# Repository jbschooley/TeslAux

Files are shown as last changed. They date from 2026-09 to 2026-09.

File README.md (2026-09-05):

# TeslAux

**Play audio from a phone through a Tesla's speakers, over USB.**

A Tesla has no aux input. It does have a USB port that accepts Tesla's own
cabin microphone — the CaraokeMic — and routes whatever that microphone hears
into the cabin speakers. TeslAux clones that microphone precisely enough that the
car accepts it, then feeds it real audio instead of a microphone.

The result is a wired audio input: anything that can play into a USB audio
output can play through the car. Wired, so unlike Bluetooth it is not
resampled, not re-encoded, and not subject to codec latency.

## How it works

```
phone ──USB──> [source board] ──I²S──> [car board] ──USB──> Tesla
               a USB audio output      a clone of the CaraokeMic
```

Two boards, because the phone and the car are both USB *hosts* — a device has to
be a USB *peripheral* to each, and one USB controller cannot do both. They are
joined by I²S, which carries the audio between them as plain PCM with no
conversion at any point.

The source board's clock is steered to follow the phone, so the phone and the
I²S link run on one clock. The only remaining clock difference — against the
car — is absorbed by varying the size of each USB packet, which loses no samples
at all.

## Build and flash

Two identical **RP2040-Zero** boards, about $3 each. Solder four signals and a
ground between them:

| source board | | car board |
|---|---|---|
| GPIO12 | → | GPIO10 (DATA) |
| GPIO11 | → | GPIO11 (BCK) |
| GPIO10 | → | GPIO12 (SHIELD) |
| GPIO9 | → | GPIO13 (LRCK) |
| GND | → | GND |

The pins are the bottom row, so the two boards can be soldered edge to edge with
one rotated 180 degrees — every pair above sums to 22, which is what facing pads
do. Four-inch jumpers were corrupting one sample in roughly every 1,400: the
right channel replaced by its own sign bit, up to 44% of full scale in a single
sample, which is audible as a pop every few minutes.

SHIELD carries no signal. The source holds it low so a driven conductor sits
between BCK and LRCK, which is where the coupling was. `rp2040/src/pins.rs` has
the measurement and refuses to build if the map stops being physically possible.

Ground is not optional — the boards are powered from different USB ports.

```sh
cd rp2040 && ./build-uf2.sh
```

Then hold BOOTSEL while plugging each board into a computer and copy its image
across. Use `cp`, not Finder: the bootloader reboots the instant the last block
lands, which Finder treats as a disk being yanked out.

```sh
# the board the phone plugs into
cp rp2040/teslamic-rp-source-ultralow.uf2 /Volumes/RPI-RP2/

# the board that plugs into the car
cp rp2040/teslamic-rp-car-elastic-lowlat.uf2 /Volumes/RPI-RP2/
```

The phone will show a USB audio output called **TeslAux Bridge**. Plug the car
board into the car's data port and the mic icon appears.

Each board has an onboard RGB LED: **green** streaming, **blue** waiting for
audio, **red** a fault. [`rp2040/FLASHING.md`](rp2040/FLASHING.md) has every
image, the LED codes in full, and the diagnostic builds.

### A simpler version is coming

A **PCM2706** USB-to-I²S bridge chip can replace the source board entirely. It is
a fixed-function part with no firmware, and it recovers the host's clock in
hardware rather than in a software control loop — which should be both more
reliable and about 5 ms lower latency than the two-board version. That leaves one
RP2040 plus a ~$10 module. The car-side firmware already supports it and follows
whatever sample rate it delivers; it has not been tested yet.

## Verified bit-exact

The two-board rig has been measured, not just listened to: **8,352,000 frames
across three consecutive cold boots, delivered from an Android phone to a Mac
through both boards, identical to the source file, sample for sample.** See `rp2040/TESTING.md` for
the method and `tools/bitcompare.py` for the tool.

## What the car accepts

Findings from the car itself, not from documentation. Several contradict what
this project believed for months — the corrections are noted.

### The device must look like a CaraokeMic

The car runs a driver written for one specific device and checks for it. Getting
the audio right is not enough; get the descriptors wrong and it shows
"unsupported USB microphone" and disconnects after about 60 seconds.

What has to match, verified against a real unit dumped over libusb
(see [`real_mic_dump.md`](real_mic_dump.md)):

* **VID `0x1235`, PID `0x0002`**, and the manufacturer, product and serial
  strings. The serial is 40 bytes, which makes the string descriptor 162 bytes —
  a 128-byte control buffer silently breaks enumeration.
* **Four interfaces**: AudioControl, AudioStreaming, and *two* HID interfaces.
* **IF2 is a HID keyboard** with the standard 65-byte boot-keyboard report
  descriptor. Not telemetry, as was assumed for months — the mic's button sends
  keystrokes.
* **IF3 is an endpoint-less vendor HID**, usage page `0xFF00`, usage `0x55AA`,
  with an exact 36-byte report descriptor and an 8-byte Feature report reading
  `00 01 00 03 03 00 08 00`. **This is the one that matters.** The car writes
  `A5 5A`-framed configuration to it and validates what comes back. Cloning it
  byte for byte is what defeats the popup.

What does *not* have to match: the endpoint numbers, the audio topology (a plain
microphone → USB-streaming terminal pair works, without the real mic's feature
and selector units), `bcdUSB`, `bcdHID`, and `wMaxPacketSize`.

### Audio formats

Retested after fixing two transport bugs that had been corrupting everything we
sent. The earlier conclusion that the car was "48 kHz-family only" was wrong —
it was our own corruption, and 44.1 kHz was simply the rate most exposed to it.

| | |
|---|---|
| 32 kHz, 44.1 kHz, 48 kHz, 16-bit | clean — retested after the transport fixes |
| 96 kHz, 16-bit | clean — retested |
| 192 kHz, 16-bit | plays, with a click roughly every 2 s (not diagnosed) |
| stereo | yes |
| more than 2 channels | only the first two are ever played |
| **24-bit** | **unverified** — see below |

**24-bit is an open question, not a result.** It was tested in July and appeared
clean at 48 and 96 kHz, but that predates the two transport bugs being found, and
those July tests used a 1 kHz tone at 48 kHz — exactly one cycle per USB packet,
and therefore blind to the packet corruption by construction. The same test
signal also reported 48 kHz as "clean" while every packet was being mangled. So
the July result carries no information either way.

`t114/teslamic-48k-24bit.uf2` and `teslamic-96k-24bit.uf2` are rebuilt against
the fixed firmware with a 997 Hz tone (deliberately not packet-periodic) if you
want to settle it. Note 192 kHz at 24-bit is impossible regardless: 1152 bytes
per frame against the 1023-byte full-speed isochronous limit.

It does not currently matter for the shipping firmware, which is 16-bit
throughout — the PCM2706 is 16-bit only, and the RP2040 path is built around
16-bit samples.

### Variable packet sizes

**The car accepts isochronous packets that change size from frame to frame.**
Verified with a build that alternates 47 and 49 samples on *every* frame, ~500×
harsher than real clock drift, playing cleanly for ten minutes.

This is what makes the design work: the difference between our clock and the
car's is absorbed by sending one more or one fewer sample when needed, so no
sample is ever dropped, duplicated or resampled.

### Latency

About 8 ms through both boards — USB frame quantisation, and enough buffer to
cover one packet at each hop.

That is not what you will hear. **The car's own audio pipeline adds roughly
100 ms**, measured in July and not reachable from the device, and the phone adds
10–50 ms of its own buffering. Our share is a few percent of the total, which is
worth knowing before optimising it further.

## Repository layout

| | |
|---|---|
| [`rp2040/`](rp2040) | the firmware to use — both boards build from one crate |
| [`t114/`](t114) | the original nRF52840 prototype, where the descriptors and the transport bugs were worked out |
| [`tools/`](tools) | UF2 packaging, and analysis scripts for recorded audio |
| [`RESEARCH.md`](RESEARCH.md) | how the CaraokeMic was reverse engineered |
| [`real_mic_dump.md`](real_mic_dump.md) | raw descriptor dump from a real unit |

## Licence

MIT throughout — see [`LICENSE`](LICENSE).

[`NOTICE.md`](NOTICE.md) records the provenance of two pieces: the T114's ST7789
driver, ported from an AGPL project and relicensed MIT here by its copyright
holder, and `tools/uf2conv.py`, from Microsoft's uf2 project.

"Tesla", "TeslaMic" and "CaraokeMic" are trademarks of Tesla, Inc. This project
is independent and not affiliated with or endorsed by Tesla.

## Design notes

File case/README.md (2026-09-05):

# Case for the soldered pair

Two RP2040-Zeros soldered end to end — castellations butted, component sides up,
a USB-C port at each outer end, the I²S link running across the joint.

```
    USB-C -> [RP2040-Zero | RP2040-Zero] <- USB-C
     phone              ^ joint             car
```

| file | triangles | size |
|---|---|---|
| `rp2040_soldered_case.stl` | 2,746 | 53.2 x 24.2 x 7.8 mm |
| `rp2040_soldered_lid.stl` | 3,490 | 53.2 x 24.2 x 7.6 mm |

53.2 x 24.2 x 9.4 mm closed. The lid is flush with the base — no lip, so the
seam is the only purchase for opening it.

## Printing

Both parts print without supports.

- **Base:** flat on the bed as oriented.
- **Lid:** outer face down, so the tabs and posts point up.

The rounded edges sit against the bed either way. A quarter round leaves the face
horizontally, so the first few layers grow outward fast — about 0.24 mm per
0.2 mm layer at the steepest, within what a 0.4 mm extrusion bridges, but slow
the first few layers if the edge comes out rough.

## Fit notes

These are the second revision, after a test print. What changed:

- The board is **0.8 mm thick, not 1.6** — measured off the real thing, which is
  why the case got shorter despite everything else growing.
- A SOT-23 on the underside beside each USB port landed on the support ring; the
  ring is now cut away 8 mm across, 9 mm in from the cavity wall at each end.
- The USB sill was too low once the thickness was corrected, and sits 0.3 mm
  below flush so a sill printed slightly proud cannot foul the connector.
- Two ribs bracing the joint from underneath fouled the crystals, which sit 4–5 mm
  either side of it. Gone; the ring's long runs carry the board across the gap.

Only the two STLs are here. The generator that produced them, and the full write
-up of the revisions, live outside this repo — worth bringing in if the case ever
needs changing, since these files cannot be regenerated without it.

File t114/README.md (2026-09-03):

# T114 / nRF52840 — the original prototype

**This is not the firmware to use.** It is where the project started, and where
the hard problems were solved: the descriptor set the car validates, and both
isochronous transport bugs. The shipping firmware is in [`../rp2040`](../rp2040).

It still works, and it is still the most car-proven code here — it has been
accepted by a real Tesla since July. It is kept because:

* it is the reference the RP2040 descriptors were copied from, byte for byte;
* it has a hardware I2S slave peripheral, so it needs no PIO, which makes it a
  useful cross-check if the RP2040's I2S is ever suspect;
* it has an onboard TFT, which is what the `usb-spy` build draws the car's USB
  control requests on. That is how the IF3 config protocol was found.

What it does **not** have is an audio input path — it emulates the mic and
generates test tones, but nothing wires I2S capture into its isochronous pump.
That work went into the RP2040 firmware instead.

Hardware: Heltec Mesh Node T114 (nRF52840 + SX1262). Flash by double-tapping
RESET and dragging a `.uf2` onto the drive that appears.

---

Firmware that makes a **Heltec Mesh Node T114** enumerate over USB as Tesla's
cabin microphone, to test whether the car will show its **MIC overlay icon**.

Identity + descriptors are cloned from the TeslaMic dump in the [r/hardwarehacking
thread](https://www.reddit.com/r/hardwarehacking/comments/1ok256p/going_down_a_rabbit_hole_wondering_where_to_start/):

| Field | Value |
|---|---|
| VID:PID | `1235:0002` |
| Manufacturer | `TeslaMic_T004_OTA_231008` |
| Product | `TeslaMic` |
| Max power | 500 mA |
| Audio | USB Audio Class 1.0 — 48 kHz, 16-bit, **stereo**, 192 B/1 ms iso IN |

## Status — WORKING ✅ (popup solved 2026-07-14)

`teslamic-hid.uf2` runs in the car with the **mic icon, working audio, and no
"unsupported USB microphone" popup / disconnect**. The HID interfaces are a
byte-exact clone of a real TeslaMic (dumped over libusb — see `real_mic_dump.md`):
IF2 is a HID keyboard, IF3 is an endpoint-less vendor HID (Usage 0x55AA) whose
report descriptor + Feature report the car validates. It also enumerates on macOS
as a 2-channel / 48 kHz input named `TeslaMic`.

Remaining work is product polish (an I²S line-in front-end to stream real audio)
and the ~100 ms **Tesla-side** latency (not fixable on the device — our end is
~1–2 ms; it's the car's audio pipeline).

Four flashable builds:

| File | Behaviour |
|---|---|
| **`teslamic.uf2`** | Enumerates **and streams silence** — 192 B of zeros per USB frame out the iso endpoint, so it looks like a mic that's actively capturing. Try this in the car. |
| **`teslamic-sine.uf2`** | Same, but emits a **1 kHz sine while the USER button (P1_10) is held**, silence when released. Each new press **alternates the channel**: press 1 = LEFT, press 2 = RIGHT, press 3 = LEFT, … (other channel silent). Good for confirming the audio path and checking L/R routing. |
| **`teslamic-hid.uf2`** | Everything: the button-triggered L/R sine **plus a HID interface (IF2) streaming an 8-byte heartbeat** — an attempt to defeat the ~60 s "unsupported USB microphone" popup (see [The popup](#the-popup-hid-heartbeat)). Built with `--features hid-heartbeat,sine-button`. |
| `teslamic-enum-only.uf2` | Enumerates only (no iso data). Fallback if a streaming build misbehaves. Tested to enumerate on macOS. |

## The popup (HID heartbeat)

The genuine TeslaMic exposes two HID interfaces (an 8-byte interrupt-IN status
stream + a control/feature "settings" interface) that this project's audio-only
builds don't. The car shows the mic icon and plays audio, but after ~60 s pops
"unsupported USB microphone" — most likely a **keepalive/telemetry watchdog**
timing out (a static descriptor check would fail instantly, not after a minute).

`teslamic-hid.uf2` adds **IF2** (8-byte interrupt IN, `poll_ms = 1`, matching the
dump) and streams a report continuously, with a rolling counter in byte 0 so a
liveness watchdog sees changing data.

**This is a blind guess.** The dump doesn't include the HID report descriptors or
the report *contents*, so if the car validates specific values (rather than just
"is something reporting"), this won't be enough — it would need a `usbhid-dump` +
USB trace from a real or clone TeslaMic. The IF3 "settings" interface is also not
implemented yet. Combine with the tone build via
`--features hid-heartbeat,sine-button` if you want to test audio and the popup
together.

Tesla: Sees the device as a microphone input and shows the mic icon. The sine wave plays through the car's audio system.

However, there is a noticeable delay (estimating around 100ms) between pressing the button and hearing the sine wave. This is much better than Bluetooth, but not instantaneous enough for real-time audio (like playing an instrument). The only way to fix this would be to get Tesla's engineers to reduce the buffering. I'm surprised they haven't done this already because the delay is noticeable when using the official Tesla Caraoke Mic.

After a minute, it disconnects and the car shows an unsupported USB microphone popup. I assume this is because the TeslaMic firmware is sending some telemetry over the HID interface that this firmware does not implement. I don't have an official or clone mic to use to reverse engineer this interface yet.

## USB spy — on-screen request logger (`teslamic-spy.uf2`)

To reverse-engineer the popup without a real mic, this build turns the T114 into
its own USB analyzer. It's the full mic + HID device (`--features usb-spy`, which
implies `hid-heartbeat`), plus a spy that **logs every USB control request the car
sends to the onboard ST7789 TFT in real time**. Flash it, plug into the car, and
watch the screen (it lights ~1.5 s after boot).

Each line is one control request/event:

```
CONFIGURED=1            device configured
SET_IF if1 alt1         host selected AudioStreaming alt-1 (starts audio)
O 21 r09 v0200 i2 l8 d05   ctrl-OUT bmReqType=0x21 bReq=0x09(SET_REPORT)
                            wValue=0x0200 iface=2 len=8 firstbyte=0x05
I a1 r01 v0100 i2 l8       ctrl-IN  bmReqType=0xA1 bReq=0x01(GET_REPORT) ...
```

`bmReqType` decodes as: `0x21` = host→device, class, interface; `0xA1` = the
device→host read. Anything the car sends to **interface 2** (our HID) — especially
`SET_REPORT`/`GET_REPORT` with their `wValue` and data byte — is the handshake
we're missing. Read those off the screen (or photograph it) right up to the popup,
and we can implement the HID interface to match instead of guessing.

Notes/limits: the spy observes **class/vendor** requests (the interesting ones) plus
config + alt-setting changes; it doesn't see plain standard requests. The screen
shows the most recent ~11 events; the ring buffer holds 32.

## Format test builds

The audio format is a **build-time parameter** (`build.rs` reads env vars), so any
feasible rate / channel count / bit depth is one build away. All these use
`sine-button`, so the tone plays while the USER button is held; each press steps
the tone to the **next channel** (at 2ch = L/R; at 4ch = cycles all four), which
is how you check the car's channel mapping.

| File | Format | Car result | Env |
|---|---|---|-----|
| `teslamic-48k-24bit.uf2` | 48 kHz / 2ch / 24 | ❔ July result is uninformative, not retested | `TESLAMIC_BITS=24` |
| `teslamic-96k.uf2` | 96 kHz / 2ch / 16 | ✅ clean | `TESLAMIC_RATE=96000` |
| `teslamic-96k-24bit.uf2` | 96 kHz / 2ch / 24 | ❔ July result is uninformative, not retested | `TESLAMIC_RATE=96000 TESLAMIC_BITS=24` |
| `teslamic-mono.uf2` | 48 kHz / 1ch / 16 | ✅ works | `TESLAMIC_CHANNELS=1` |
| `teslamic-sweep.uf2` | 48 kHz / 2ch / 24, **freq sweep** | ❔ measured under the transport bugs | `--features sweep TESLAMIC_BITS=24` |
| `teslamic-44k.uf2` | 44.1 kHz / 2ch / 16 | ✅ **clean** (retested 2026-09-02) | `TESLAMIC_RATE=44100` |
| `teslamic-32k.uf2` | 32 kHz / 2ch / 16 | ✅ clean (retested 2026-09-02) | `TESLAMIC_RATE=32000` |
| `teslamic-44k-24bit.uf2` | 44.1 kHz / 2ch / 24 | ❔ not retested since the fixes | `TESLAMIC_RATE=44100 TESLAMIC_BITS=24` |
| `teslamic-4ch.uf2` | 48 kHz / 4ch / 16 | ⚠️ only ch 1–2 play | `TESLAMIC_CHANNELS=4` |
| `teslamic-96k-4ch.uf2` | 96 kHz / 4ch / 16 | ⚠️ only ch 1–2 play | `TESLAMIC_RATE=96000 TESLAMIC_CHANNELS=4` |
| `teslamic-5ch.uf2` | 48 kHz / **5.0 surround** / 16 | ⚠️ only ch 1–2 play | `TESLAMIC_CHANNELS=5 TESLAMIC_CHMASK=0x37` |
| `teslamic-192k.uf2` | 192 kHz / 2ch / 16  | ❔ "no output" in July; not retested since the fixes | `TESLAMIC_RATE=192000` |

Column key: ✅ works cleanly · ⚠️ works with a caveat · ❌ no audio.

### What the results tell us

> **Corrected 2026-09-02.** The original matrix was measured with two firmware
> bugs present (an ISO-IN DMA race, and nRF52840 erratum 166 unapplied). Both
> corrupted the audio *we* transmitted, so several "Tesla can't do this"
> conclusions were actually our own faults. Rates marked ❔ were measured under
> those bugs and have not been retested.

- **Tesla is NOT 48 kHz-family only.** With the transport fixed, **32 kHz,
  44.1 kHz, 48 kHz and 96 kHz all play cleanly.** The old "44.1 kHz buzzes"
  finding was our bug: 44.1 is the one standard rate that doesn't divide into
  1 ms frames, so it alternates 44/45 samples per packet, and varying the packet
  size was exactly what the two bugs corrupted.
- **Variable packet sizes are fine.** `teslamic-stress-variable.uf2` changes the
  packet size on *every frame* — ~500x harsher than real clock drift — and plays
  clean. Elastic pacing against a drifting source is therefore viable.
- **Tesla is stereo-max.** Every multichannel build (4ch / 5ch) plays only the
  first two channels. Measured before the fixes, but the fixes cannot plausibly
  affect channel *mapping*, so this one still stands.
- **Not heavily processed.** The 50 Hz–20 kHz sweep comes through full-range with
  no obvious roll-off, so the car isn't aggressively band-limiting the mic input —
  promising for piping real/music audio, not just voice.
- **Recommended format: 48 kHz stereo 16-bit** — not because the others fail,
  but because it is exactly what the real TeslaMic advertises.

`TESLAMIC_CHMASK` overrides the `wChannelConfig` spatial-position bitmap (default =
low `channels` bits). The **sweep** build ignores per-channel stepping: while the
button is held it steps a tone through 50 Hz → 20 kHz on all channels (~0.35 s
each, restarting each hold), so you can hear where the car's processing rolls off.

Build any format: `TESLAMIC_RATE=… TESLAMIC_CHANNELS=… TESLAMIC_BITS=… cargo build --release --features sine-button` (defaults 48000 / 2 / 16).

**Hardware limit:** the nRF52840 USB is full-speed, so one isochronous packet is
≤ 1023 bytes/frame — i.e. `(rate/1000) × channels × (bits/8) ≤ 1023`. `build.rs`
rejects anything over that at compile time. Consequences: 192 kHz caps at 2ch/16-bit,
4ch caps at 96 kHz, and 24-bit caps at 96 kHz/2ch. (192 kHz/4ch, 96 kHz/8ch, and
192 kHz/24-bit are impossible on this chip.)

## Build

Requires the Rust toolchain (pinned in `rust-toolchain.toml`) and
`arm-none-eabi-objcopy` (from `arm-none-eabi-gcc` / `brew install arm-none-eabi-gcc`).

Each build is a Cargo feature of the same source. Compile, then wrap the ELF
into a UF2 at the app offset `0x26000`:

```sh
# pick ONE build:
cargo build --release                          # -> silence  (teslamic.uf2)
cargo build --release --features sine-button   # -> sine/button (teslamic-sine.uf2)
cargo build --release --features hid-heartbeat,sine-button # -> button sine + HID heartbeat (teslamic-hid.uf2)
cargo build --release --no-default-features     # -> enumerate only (teslamic-enum-only.uf2)

# then package the resulting ELF:
arm-none-eabi-objcopy -O binary \
    target/thumbv7em-none-eabihf/release/teslamic teslamic.bin
python3 ../tools/uf2conv.py teslamic.bin -c -b 0x26000 -f 0xADA52840 -o teslamic.uf2
```

All four prebuilt `*.uf2` files are checked in.

## Flash it (no debug probe needed)

The T114 ships with the Adafruit/Nordic UF2 bootloader.

1. **Double-tap the RESET button** on the T114. A USB drive named something like
   `T114BOOT` / `NRF52BOOT` appears on your Mac.
2. **Drag `teslamic.uf2` onto that drive.** The board reboots into the firmware.
3. Plug it into the car's USB port (the data port — glovebox or center console).
   If the icon doesn't appear, try toggling the screen (scroll-wheel reboot) with
   it plugged in.

To check enumeration on your Mac first: plug the board into the Mac and run
`system_profiler SPUSBDataType | grep -A12 TeslaMic` — you should see
`TeslaMic`, `0x1235`, `0x0002`, and an "Audio" interface.

## Restore Meshtastic

The app lives at `0x26000` and never touches the bootloader or SoftDevice, so
recovery is just flashing the stock image back:

1. Double-tap RESET → bootloader drive.
2. Drag the **Meshtastic T114 UF2** back on (download from the Meshtastic web
   flasher / releases). Done.

Nothing here erases the bootloader, so the board can't be bricked by a bad app
UF2 — worst case you double-tap and flash something else.

## How the silence stream works (and how to make it real audio)

`embassy-nrf` 0.10 can *allocate* the nRF52840's isochronous endpoint (so the
mic enumerates), but its `EndpointIn::write` asserts `len <= 64` and drives the
regular EPIN registers — it **cannot** push 192-byte iso packets out of the ISO
endpoint. So `iso_silence_pump()` in `src/main.rs` drives the `USBD.ISOIN`
registers directly (via `embassy_nrf::pac`, behind the `unstable-pac` feature):

- Waits until the host selects AudioStreaming alt-1 (embassy sets `EPINEN` bit 8).
- Arms `ISOIN.PTR`/`ISOIN.MAXCNT` with a 192-byte buffer and triggers
  `TASKS_STARTISOIN` **exactly once per frame, right after `EVENTS_SOF`**.
  This timing is critical: a full-speed 192-byte packet takes ~128 µs to clock
  out, and firing `STARTISOIN` (which DMAs into the single ISO buffer) while
  that transmission is in flight corrupts the packet — audible as scratchiness.
  Arming just after SOF guarantees the DMA finishes before the host's IN token
  and never during a transmission. embassy's USB driver never touches these
  registers, so there's no conflict with its interrupt handler.

**To carry real audio** instead of silence: capture stereo 48 kHz/16-bit into a
RAM ring buffer with the nRF52840's **I²S** (external ADC/line-in — cleanest),
**PDM** (digital MEMS mics), or **SAADC** (analog line-in), and point the pump's
`arm_iso` at the ring buffer's read cursor instead of the zero buffer. The USB
side is already done; only the capture front-end and a few free header pins are
needed. (`ISOINCONFIG.RESPONSE` is set to `ZERO_DATA` so any late frame sends a
harmless zero-length packet rather than stalling.)

## Design notes

- **No SoftDevice.** We never call `sd_softdevice_enable`, so the stock SD stays
  dormant and the app owns CLOCK + POWER — letting us use embassy-nrf's ordinary
  USB driver + `HardwareVbusDetect`. We force HFXO (external crystal) because the
  USB peripheral needs the crystal-derived 48 MHz reference.
- **Endpoint address.** The genuine device uses iso IN `0x84`; the nRF only has
  one iso endpoint, so ours is `0x88`. Hosts key on interface class + audio
  format, not the endpoint number.
- All descriptor byte layouts are in `src/main.rs`, annotated against the USB
  Audio Class 1.0 spec.

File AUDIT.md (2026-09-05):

# Audit: what else can interrupt the audio

Prompted by pops the buffer counters showed nothing for. Everything below is a
path that can produce a discontinuity, ranked by how easily it fires.

## Fixed here

**The rate detector could mute on one bad measurement.** `classify()` rejects
anything more than 2% from a standard rate, and an unclassifiable result muted
the output until the next window closed — up to a second of silence.

The window is easy to spoil, because the detector is clocked by *delivered
packets* rather than by time. `on_usb_frame()` only advances when the host takes
a packet, so a host that pauses polling stops the clock while the I2S side keeps
counting frames, and the ratio comes out inflated through no fault of the
source. Muting now needs three consecutive nonsense windows, and a rate change
two agreeing ones — the same rule the re-enumeration path already used.

## Remaining discontinuity sources, and why each is left alone

| Path | When it fires | Verdict |
|---|---|---|
| `trim_to_target()` on stream open | host selects alt 1 after a gap | discards down to target; **present in the build measured click-free**, so not the cause, but it is the only deliberately lossy path left |
| `push()` overrun | pipe full — the host is not draining | drops oldest, which is right: staying live beats keeping stale audio |
| `pop()` underrun | pipe dry | holds the last sample, a smaller discontinuity than jumping to zero |
| `reset()` on a 200 ms capture gap | source really stopped | deliberate: splicing stale audio onto new is worse |
| `MUTED` → `fill(0)` | rate mismatch confirmed | now needs three windows |

## Not a suspect: the elastic pacing

Varying the packet size between 47 and 49 frames **loses no samples**. It is the
mechanism that absorbs the clock difference without dropping or duplicating
anything, and it was verified bit-exact across three cold boots. Worth stating
plainly because it looks like the obvious culprit and is not.

## Measured, and clean

During a click, with logging on the single-chip build: zero underruns, overrun
and timeout counts unchanged, the car polling, the phone delivering, level inside
the deadband. **Whatever is heard does not pass through the buffer.** That is
what moved the search to the wiring and to the wire protocol.

## Cleanups made

* Removed unused imports and initialisers the loop immediately overwrites.
* `#![allow(dead_code)]` on `status.rs`, `teslamic.rs` and `i2s_pio.rs`, each with
  a note saying why: they are shared between binaries that use different subsets,
  so unused items are a property of the caller.
* The car build is now warning-free.

## What the measurements found

Everything below is measured, not inferred. Recordings were compared against the
file that was played (`tools/bitcompare.py`) or against the tone the firmware
generates (`tools/tonecompare.py`).

**The pops were line coupling, and they are fixed.** An eleven-minute recording
held 112 corrupted samples in its first two and a half minutes. All but one were
the right channel, and every one had been replaced by its own sign bit —
`(sample & 0xFFFF) >> 15` exactly, on all 54 checked by hand — with jumps up to
44% of full scale in a single sample. That is a right slot read fifteen
bit-clocks early: fifteen bits of the left slot's zero padding, then one bit of
the real sample, which happens when `wait 1 pin` on LRCK releases before the
true edge. LRCK idles low during the left slot, so only a positive glitch
corrupts the right channel, which is why the damage was one-sided.

Soldering the boards edge to edge with a driven shield between BCK and LRCK
removed it: **zero corrupted samples across five recordings since**, against 112
in two and a half minutes before.

**The remaining artifact is a 16-frame hold, and it is not the buffer.** Three
per ten minutes at first, each a sample held for 0.33 ms. Doubling the source's
cushion changed nothing (3 -> 3); doubling the car's changed nothing (3 -> 3).
The hold stayed exactly 16 frames while the source's I2S block moved 16 -> 32
and the car's moved 16 -> 64, so it is not either board's block size.

`packet-stress`, which generates a tone with no phone, no source board and no
I2S, ran **411 seconds without a single frame added, dropped or altered** —
while swinging packet sizes 47/49 every frame. That clears the USB transmit
path, the variable packet sizing, and the capture on the Mac.

`pipe-tone`, which substitutes a known tone for the captured samples while
keeping the capture timing, then put the holds in the car board's own pipe:
three in eight minutes with the I2S data discarded, so none of them could have
arrived from the source.

**Then it stopped reproducing.** Nearly thirty minutes across three
configurations, zero holds:

| car build | source build | duration | holds |
|---|---|---|---|
| `pipe-tone` | before the idle fix | 7.9 min | **3** |
| `pipe-tone` + `pipe-watch` | before the idle fix | 9.6 min | 0 |
| `pipe-tone` + `pipe-watch` | after | 10.1 min | 0 |
| `pipe-tone` | after | 10.2 min | 0 |

At the original rate, thirty clean minutes is about a 1-in-90,000 outcome, so
something did change. But no single variable explains it: the instrumentation
cannot be the cause, because the last run has none; and the idle fix cannot be
the whole cause, because the second run predates it.

The idle fix is still the best mechanism on offer. Before it, a momentary
starvation of the source's pipe un-primed it, the steering loop read a whole
target low, and the I2S clock wound down to 47488 Hz — at which the car's pipe
loses 512 frames a second and underruns about a quarter of a second later. That
chain produces exactly this artifact, from a cause on the source board, showing
up on the car board, with neither board's buffer able to prevent it. It is also
consistent with the counts falling as the source's cushion grew (6 -> 3) while
the car's made no difference.

What no hypothesis has explained is why the hold was **exactly 16 frames every
time**, across four different block-size configurations. That remains open.

## Where it ended

The shipping pairing — `car-elastic-lowlat` and `source-ultralow`, the same two
images that showed six holds in `cap2` — was recorded against the full
eleven-minute reference after the shield, the idle fix and the rate-detector
fix:

    compared 30876800 frames (643.3 s), lead-in included
    PASS  bit-exact: every sample matches

Every sample of the entire reference, including the two seconds the anchor used
to hide. No corrupted samples, no holds, no missing frames, no startup
transient.

One run does not prove a rare fault is gone, and the hold was always rare — but
at `cap2`'s rate this recording should have contained about five, and the
configuration is the one that produced them. Taken with the thirty clean minutes
of tone before it, the artifact is no longer reproducible by any means available
here.

Two of the three faults are closed by measurement rather than argument: the
sign-bit corruption (a physical fix, confirmed by its absence across six
recordings) and the idle buzz (a firmware fix with a mechanism). The third is
recorded here as unreproducible rather than solved, because that is what the
evidence supports.

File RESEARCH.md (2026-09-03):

# TeslaMic reverse-engineering — findings & next steps

Everything we've learned about Tesla's USB cabin-mic (`TeslaMic`, VID `1235:0002`)
from emulating it on a Heltec T114, and the exact plan for finishing the job once
a real mic + USB sniffer are in hand. Source thread:
<https://www.reddit.com/r/hardwarehacking/comments/1ok256p/going_down_a_rabbit_hole_wondering_where_to_start/>

---

## 1. Device identity (from the Reddit dump, confirmed by our emulator)

| Field | Value |
|---|---|
| VID:PID | `1235:0002` (registered to Focusrite/Novation — TeslaMic borrows it) |
| Manufacturer string | `TeslaMic_T004_OTA_231008` |
| Product string | `TeslaMic` |
| Max power | 500 mA, bus-powered |
| Interface tree | **4 interfaces**: IF0 AudioControl, IF1 AudioStreaming, IF2 HID, IF3 HID |
| Audio | USB Audio Class 1.0, iso IN, 192 B / 1 ms → 48 kHz / 16-bit / stereo |
| IF2 HID | 8-byte interrupt IN, 1 ms — "status telemetry" |
| IF3 HID | second HID — the **settings / OTA config** channel |

The `_OTA_` in the manufacturer string + the config protocol below → IF3 is a
firmware/config channel.

---

## 2. What our emulator achieved (all working)

- **Mic icon appears** in the car; audio plays through the cabin speakers.
- Enumerates on macOS as a 2-ch / 48 kHz input, with the IF2/IF3 HID interfaces.
- **Format support (RETESTED 2026-09-02, after fixing the ISO-IN DMA race and
  applying nRF52840 erratum 166)** — Tesla is **stereo, but not rate-fussy**:
  32 k, 44.1 k, 48 k and 96 k all play clean. The earlier readings below were
  taken with those two bugs present and were measuring our own corruption:
  - 48 kHz & 96 kHz at 16-bit: clean.
  - **24-bit: NOT established.** The July "clean" reading was taken with both
    transport bugs present, using a 1 kHz tone at 48 kHz — one cycle per USB
    packet, and so blind to the packet rotation by construction. That same
    signal called 48 kHz clean while every packet was being corrupted, so it
    proves nothing about 24-bit either. Rebuilt 24-bit images with a 997 Hz tone
    are in `t114/` if it is worth settling.
  - 192 kHz: no output (beyond the car's max rate).
  - 44.1 kHz: **clean** (the July "buzzes" reading was our fractional-packet
    handling being corrupted, not the car resampling).
  - >2 channels (4ch/5ch): only the first 2 channels ever play → stereo-max.
  - Frequency sweep 50 Hz–20 kHz came through full-range → **not heavily
    band-limited** (good for real/music audio, not just voice).
  - **Recommended format: 48 kHz stereo 16-bit** — what the real mic uses.
- ~100 ms button-to-sound latency is Tesla's own audio buffering, not the device.

---

## 3. The "unsupported USB microphone" popup — SOLVED ✅ (2026-07-14)

**Root cause:** our HID descriptors didn't match a real TeslaMic. Dumping a
working clone over libusb (see `real_mic_dump.md`) showed IF2 is a HID **keyboard**
and IF3 is an **endpoint-less** vendor HID (Usage 0x55AA) with a specific 36-byte
report descriptor + 8-byte Feature report `0001000303000800` that the car
validates. Cloning those exactly (plus the serial) → the car accepts it with **no
popup**. History of the investigation is kept below for reference.

The car shows the icon + plays audio, then (before the fix) after **~60 s** popped
"unsupported USB microphone" and disconnected.

### 3.1 What we tried (all still popped)
1. Enumeration only.
2. + HID heartbeat on IF2 (rolling counter).
3. + HID request handler (answer GET_REPORT/SET_REPORT instead of STALL).
4. + **IF3** (second HID interface) — this changed the car's behavior a lot (see below), but still popped.

### 3.2 The full control-channel handshake (captured with our on-screen USB spy)

We built `teslamic-spy.uf2` (feature `usb-spy`) — it logs every USB **control**
request the car sends to the onboard TFT. Complete captured connect sequence:

```
SET_IF if0 alt0
SET_IF if1 alt0
SET_IF if2 alt0
SET_IF if3 alt0
CONFIGURED=1
O 21 r0a v0000 i2 l0        SET_IDLE → IF2
I 81 r06 v2200 i2 l121      GET_DESCRIPTOR(HID Report) IF2, wLength = 0x121 = 289
O 21 r0a v0000 i3 l0        SET_IDLE → IF3
I 81 r06 v2200 i3 l121      GET_DESCRIPTOR(HID Report) IF3, wLength = 289
  (SET_IDLE + GET-report-desc on IF3 sometimes repeats once)
S i3 l9  a5 5a fc 04 b0 b0 00 00 f1 (16?)   SET_REPORT → IF3 (Output report, wValue 0x0200)
S i3 l9  a5 5a fc 04 b0 b0 00 10 (01 16?)
S i3 l9  a5 5a fc 04 b0 b0 00 20 (01 16?)
S i3 l8  a5 5a fc 03 c0 aa 01 (16?)
S i3 l12 a5 5a 00 07 31 00 01 02 02 17 00 (16?)
S i3 l18 a5 5a 01 0d ff 00 00 00 00 01 00 80 00 10 00 00 (16?)
  ... then only AudioStreaming alt1/alt0 toggling forever.
  NO GET_REPORT read-back after the writes.
```
(Bytes in parens are uncertain — read off blurry photos of a 240×135 screen;
verify against a real capture. Several frames appear to end in `16`, possibly a
checksum/terminator.)

Request decoding: `bmRequestType` `0x21` = host→device/class/interface,
`0x81` = device→host/standard/interface, `0xA1` = device→host/class/interface.
`bReq` `0x0a`=SET_IDLE, `0x06`=GET_DESCRIPTOR, `0x09`=SET_REPORT, `0x01`=GET_REPORT.
`wValue` `0x2200` = HID Report descriptor; `0x0200` = Output report, ID 0.

### 3.3 The IF3 config protocol (`A5 5A` framed)
- Magic header **`A5 5A`**, then a command/type byte (`fc`, `00`, `01`, …).
- The `fc 04 b0 b0 00 NN` frames look like **offset-addressed chunked writes**
  (offset `0x0000` → `0x0010` → `0x0020`, +0x10 each). Likely writing a config or
  parameter blob in 16-byte chunks.
- Variable report lengths (9, 8, 12, 18 bytes) → multiple message/command types.
- We `Accept` every write; the car never reads back over the control channel.

### 3.4 Why we're blocked (the wall)
Because there's **no `GET_REPORT` after the writes**, the accept/reject decision
happens on channels our device-side control spy **cannot observe**:
1. **The interrupt-IN endpoints** (IF2 8-byte telemetry, and possibly IF3). The
   car polls these over *interrupt* transfers, which are **not** control requests,
   so the spy can't see them. The real mic answers with specific `A5 5A`
   status/ACK reports; our rolling-counter heartbeat doesn't match → the ~60 s
   watchdog fails.
2. **The 289-byte HID report descriptor content**, which defines those report
   formats. Ours is a 21-byte generic stub; we can't reconstruct 289 bytes blind.
   (Note: the car requests 289 bytes even though our HID descriptor advertises 21
   → it has a **TeslaMic-specific driver with hardcoded expectations**.)

Both require observing a **real mic** — this is the limit of blind RE.

---

## 4. NEXT STEPS — when the mic + sniffer arrive

### 4.1 Buy
- A genuine or clone **TeslaMic / Caraoke mic / PureMic**.
- **Stage 1 (free):** any **Linux** box (Raspberry Pi 4/5 ideal) for usbmon/usbhid-dump.
- **Stage 2 (inline capture):** **Cynthion** (Great Scott Gadgets, ~$150) — USB 2.0
  full-speed analyzer, Wireshark support. (Or Total Phase Beagle USB 12, ~$400+.)
  Avoid generic $20 "USB analyzers".

### 4.2 Stage 1 — dump the mic on Linux (gets most of what we need)
```sh
lsusb -v -d 1235:0002                 # full descriptors, HID descriptor lengths
sudo usbhid-dump -d 1235:0002         # the actual 289-byte report descriptors (IF2 + IF3)  <-- KEY
sudo modprobe usbmon
# then capture in Wireshark on the usbmonN interface for the mic's bus while
# plugging the mic in; watch the interrupt-IN reports the mic sends unprompted.
```
Save the report-descriptor bytes and any interrupt-IN report payloads.

### 4.3 Stage 2 — sniff the car ↔ mic exchange (Cynthion inline)
Put the analyzer between the car's USB port and the real mic. Capture a full
session (connect → ~60 s). Extract, in order:
1. The **IF2 & IF3 interrupt-IN reports** the mic sends (format + cadence) — this
   is what our watchdog-failing heartbeat must match.
2. The car's `A5 5A` **SET_REPORT** writes to IF3 **and the mic's response** (does
   it ACK on IF3 interrupt-IN? with what?).
3. Whether the mic's reports are `A5 5A`-framed (likely) and their exact fields.

### 4.4 Then implement in this firmware
- Replace `HID_REPORT_DESCRIPTOR` (currently a 21-byte stub in `t114/src/main.rs`) with
  the real 289-byte descriptor(s) for IF2 and IF3.
- Replace the rolling-counter heartbeat with the mic's real IF2 telemetry report(s).
- Handle the IF3 `A5 5A` config writes and emit the correct ACK/status on IF3.
- Re-test in the car; the ~60 s watchdog should then be satisfied.

The `usb-spy` build stays useful throughout for confirming the car's control-side
behavior matches.

---

## 5. Emulator build reference (this repo)

Firmware for the Heltec T114 (nRF52840), Rust/embassy, flashes via UF2
(double-tap RESET → drag the `.uf2`). See `README.md` for the full build/flash/
format-matrix details. Key builds:

| UF2 | Purpose |
|-----|---|
| `teslamic.uf2` | mic + silence |
| `teslamic-sine.uf2` | mic + button tone (L/R per press) |
| `teslamic-hid.uf2` | mic + 2 HID interfaces + heartbeat (popup attempt) |
| `teslamic-spy.uf2` | **USB control-request logger on the onboard TFT** (the RE tool) |
| `teslamic-{44k,96k,192k,mono,4ch,5ch,*-24bit,sweep}.uf2` | format tests |

Audio format is a build-time knob: `TESLAMIC_RATE/CHANNELS/BITS/CHMASK`.
`teslamic-spy.uf2` shows the newest ~15 control events; it suppresses the
audio-alt and SET_REPORT floods so the handshake stays visible.

Reminder of the physics limit: nRF52840 USB is **full-speed**, so one iso packet
is ≤ 1023 bytes/frame — `(rate/1000) × channels × bytes ≤ 1023` (enforced in
`build.rs`). embassy-nrf 0.10 can't write the iso endpoint via its driver, so the
firmware drives the `USBD.ISOIN` registers directly, armed once per SOF.

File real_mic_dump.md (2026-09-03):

# Real TeslaMic (clone) USB dump — 2026-07-14

Dumped from a working clone `TeslaMic` (VID `1235:0002`) on macOS via libusb.
This is the definitive replication target. Manufacturer string of this unit:
`TeslaMic_V004_FW_20220217Tes` (a different FW rev than the Reddit `T004_OTA_231008`).

## Raw descriptors (hex)

```
DEVICE  120110010000004035120200000101020301
CONFIG  0902a30004010080fa 090400000001010000 09240100012f000101
        0c2402040102000203000000 0a240605040101020200 07240506010500
        092403070101000600 090401000000010200 000904010101010200
        0007240107010100 0e2402010202100244ac0080bb00 09058409c000010000
        07250101000000 090402000103000000 09210102000122410007058103400001
        090403000003000000 092101020001222400
IF2_REPORT (65 B, HID keyboard)
        05010906a101050719e029e71500250175019508810295017508810195057501
        050819012905910295017503910195067508150026a400050719002aa4008100c0
IF3_REPORT (36 B, vendor)
        0600ff0aaa55a101150026ff007508960001090181029600010901910295080901b102c0
IF3 Feature report (GET_REPORT feature, 8 B)  0001000303000800
IF2 Input report (no key)  00
iSerialNumber (40 B, per-session random) e.g. 0E02070008181F0B8AFB76F93A8C1B1D472AA0AA0C2535898B4D6A4738FAD0057B6A12DB17320B75
```

## Decoded

### Device descriptor
bcdUSB **0x0110** · bMaxPacketSize0 64 · VID `1235` PID `0002` · bcdDevice `0x0100`
· iMfr/iProd/iSerial = 1/2/3 · 1 config

### Config (163 B, 4 interfaces, bus-powered, 500 mA)

**IF0 — AudioControl** (class 1/1, 0 ep). Topology:
Input Terminal **4** (Microphone, 2ch, L+R) → Feature Unit **5** (master **mute**,
ch1/ch2 **volume**) → Selector Unit **6** → Output Terminal **7** (USB streaming).
- HEADER: bcdADC 1.00, wTotalLength 47
- INPUT_TERMINAL: id 4, type 0x0201, 2ch, chcfg 0x0003
- FEATURE_UNIT: id 5, src 4, controlSize 1, controls [master 0x01, ch1 0x02, ch2 0x02]
- SELECTOR_UNIT: id 6, 1 pin, src 5
- OUTPUT_TERMINAL: id 7, type 0x0101, src 6

**IF1 — AudioStreaming** (class 1/2): alt0 zero-bandwidth, alt1 active.
- AS_GENERAL: bTerminalLink 7, bDelay 1, PCM
- FORMAT_TYPE_I: 2ch, 2 B/subframe, 16-bit, **2 sample rates: 44100 & 48000**
- EP `0x84` iso **adaptive** (attr 0x09), 192 B, interval 1, (bRefresh/bSynch 0)
- CS_EP: **sampling-frequency control** enabled (bmAttributes 0x01)

**IF2 — HID keyboard** (class 3/0): standard boot-keyboard report descriptor
(65 B), interrupt IN EP `0x81`, 64 B, interval 1. (The mic's physical button →
keystrokes.)

**IF3 — HID vendor** (class 3/0, **0 endpoints**): report descriptor 36 B —
Usage Page 0xFF00, top **Usage 0x55AA**, with a **256-B Input report**, **256-B
Output report**, and **8-B Feature report** (all Usage 0x01, report ID 0). This
is the config/OTA channel: the car writes `A5 5A`-framed data to the 256-B
**Output** report via `SET_REPORT (wValue 0x0200)`. Its **Feature report reads
back `00 01 00 03 03 00 08 00`**.

## What this means for the emulator (what we had WRONG)
- bcdUSB should be 0x0110 (we sent 0x0200) — minor.
- **IF2 must be a real HID keyboard** (65-B descriptor) — we sent an 8-B vendor blob.
- **IF3 must be endpoint-less** with the exact 36-B vendor descriptor + 256/256/8
  In/Out/Feature reports — we gave it an interrupt-IN endpoint + 21-B stub.
- Audio needs the **Feature Unit + Selector Unit** and terminal IDs 4/5/6/7, plus
  **two sample rates** and sampling-freq control — we had a bare mic→USB pair.
- Add a serial number string; return the IF3 Feature report `0001000303000800`.

The car validates these descriptors (esp. IF3's), so matching them exactly is the
path to defeating the popup. See the plan being implemented in `t114/src/main.rs`.

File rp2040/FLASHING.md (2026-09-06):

# What to flash on which board

Two RP2040-Zero boards. They are **not** interchangeable once flashed — one
faces the phone, one faces the car.

```
phone ──USB-C──> [SOURCE board] ──I²S──> [CAR board] ──USB-C──> Tesla
```

## Wiring between the boards

| source board | | car board |
|---|---|---|
| GPIO12 | → | GPIO10 (DATA) |
| GPIO11 | → | GPIO11 (BCK) |
| GPIO10 | → | GPIO12 (SHIELD) |
| GPIO9 | → | GPIO13 (LRCK) |
| GND | → | GND |

The pins are the bottom row, so the two boards can be soldered edge to edge with
one rotated 180 degrees — every pair above sums to 22, which is what facing pads
do. Four-inch jumpers were corrupting one sample in roughly every 1,400: the
right channel replaced by its own sign bit, up to 44% of full scale in a single
sample, which is audible as a pop every few minutes.

SHIELD carries no signal. The source holds it low so a driven conductor sits
between BCK and LRCK, which is where the coupling was. `rp2040/src/pins.rs` has
the measurement and refuses to build if the map stops being physically possible.

**Ground is not optional.** The boards are powered from different USB ports;
without a common reference the I²S has nothing to switch against.

## Flash these

Hold BOOTSEL while plugging the board into your Mac, then:

```sh
# SOURCE board — the one the phone plugs into
cp rp2040/teslamic-rp-source-ultralow.uf2 /Volumes/RPI-RP2/

# CAR board — the one that plugs into the Tesla
cp rp2040/teslamic-rp-car-elastic-lowlat.uf2 /Volumes/RPI-RP2/
```

Copy from the terminal, not Finder — Finder crashes on `RPI-RP2` because the
bootloader reboots and unmounts the volume the moment the last block lands.

## Reading the LED (WS2812 on GPIO16)

| colour | source board | car board |
|---|---|---|
| green | streaming | streaming |
| blue | no audio from the host yet, or paused | no I²S clock arriving |
| red | — | muted: source rate is not 48 kHz, or a packet exceeded wMaxPacketSize |
| amber | correcting drift more than expected | — |
| magenta | boot indicator, should turn green/blue quickly | same |

## All images

### Shipping

| image | board | notes |
|---|---|---|
| `teslamic-rp-source-ultralow.uf2` | source | 2.7 ms cushion — sized at 2x the *measured* peak excursion (<64 frames over a full track) |
| `teslamic-rp-source-steered-lowlat.uf2` | source | **safe default.** Clock steered to the host, 5.3 ms cushion |
| `teslamic-rp-source-steered.uf2` | source | same, 10.7 ms cushion — more margin |
| `teslamic-rp-source-adaptive.uf2` | source | fallback: upstream I²S master, free-running clock, uses slip correction |
| `teslamic-rp-source-lowlat.uf2` | source | as adaptive, halved cushion |
| `teslamic-rp-car-elastic-lowlat.uf2` | car | **recommended.** 2.7 ms cushion |
| `teslamic-rp-car-elastic.uf2` | car | same, 5.3 ms cushion — more margin |
| `teslamic-rp-car-pcm2706.uf2` | car | identical to `car-elastic`; kept under its own name for the PCM2706 build |
| `teslamic-rp-car-locked.uf2` | car | clock-locked pairing. Its source counterpart is deliberately not built |

### Diagnostics

Flash these only while chasing a fault. Several do not enumerate as USB at all,
which is expected.

| image | board | answers |
|---|---|---|
| `teslamic-rp-LEDTEST.uf2` | either | is the WS2812 driver, PIO program and pin correct? Cycles colours |
| `teslamic-rp-I2SSNIFF.uf2` | car | is a clock arriving? Plain GPIO edge counting, no PIO |
| `teslamic-rp-I2SRX.uf2` | car | does `slave_rx` produce samples? red stalled / amber all-zero / green real data |
| `teslamic-rp-I2STEST.uf2` | source | drives the link with embassy-rp's upstream I²S master, to test `slave_rx` against known-good code |
| `teslamic-rp-source-PANTEST.uf2` | source | which side does I²S slot 0 come out of? Tone in slot 0, silence in slot 1 |
| `teslamic-rp-source-MEASURE.uf2` | source | how far does the buffer actually wander? LED: green <64 frames, amber <128, red >=128. Run a full song; the peak is the real lower bound on the cushion |
| `teslamic-rp-car-BOOTDETACH.uf2` | car | as `car-elastic-lowlat`, plus: **hold BOOTSEL to drop off the car's USB bus**. The car clamps all media to ~60% whenever an audio input is present and decides that when the volume is set — so hold the button, set the volume, release, and it stays loud |
| `teslamic-rp-car-STRESS-TEST.uf2` | car | does the car accept variable packet sizes? Self-contained, needs no wiring |
| `teslamic-rp-car-PIPEWATCH.uf2` | car | **how** does the pipe empty? Same tone as PIPETONE plus the measurement. LED latches on the first underrun: green none yet, **red** the producer stalled (level fell below the pacer's floor and hit zero within 10 ms), **amber** in between, **blue** a gradual drain the pacer failed to answer (50 ms+) |
| `teslamic-rp-car-PIPETONE.uf2` | car | is a hold coming from THIS board's pipe, or arriving over I²S? Substitutes a known tone for the captured samples while keeping the capture timing. Needs the source board connected and streaming; check with `tools/tonecompare.py` |

**Start with the isolation builds, not with a theory.** Every hard bug in this
project was found by taking one variable out of the path; several hours were
lost to reasoning first.

## Known non-issue

Gig Performer displays this device's two channels swapped. The firmware is
correct — `PANTEST` shows I²S slot 0 arriving on the left, and the car plays the
correct side. It is Gig Performer's channel labelling.

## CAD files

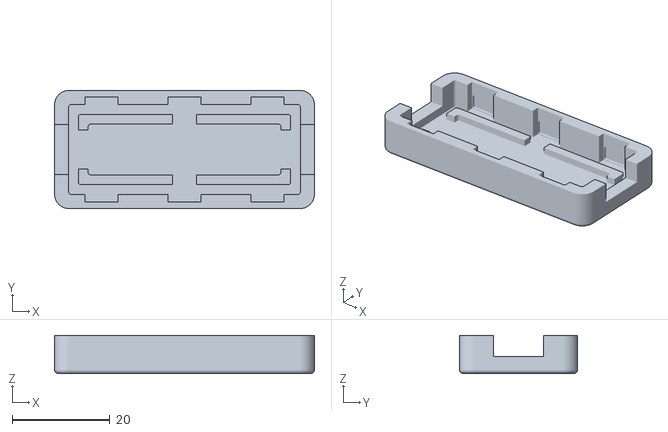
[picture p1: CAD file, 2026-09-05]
case/rp2040_soldered_case.stl
53.2 x 24.2 x 7.80

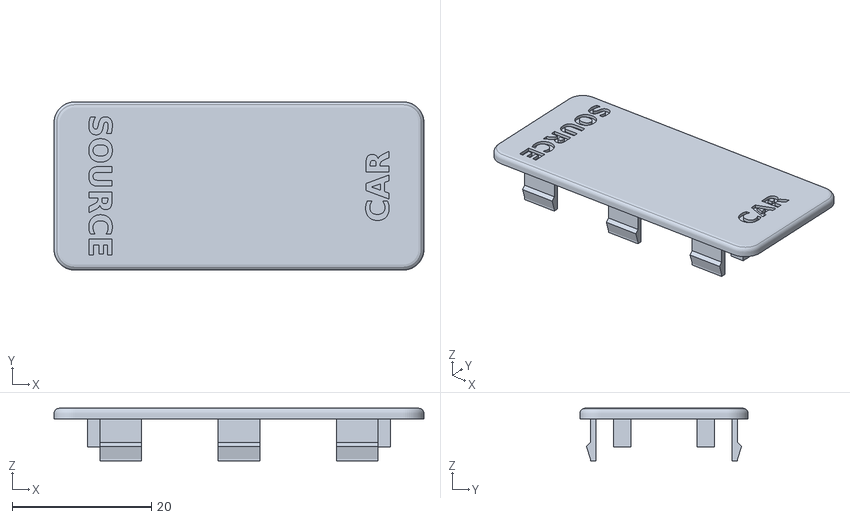
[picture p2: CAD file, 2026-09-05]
case/rp2040_soldered_lid.stl
53.2 x 24.2 x 7.60

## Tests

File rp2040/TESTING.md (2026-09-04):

# Builds, pairings, and the two open questions

> ## Status 2026-09-03
>
> **The RP2040 car board is accepted by the car.** `teslamic-rp-car-STRESS-TEST.uf2`
> played a 997 Hz tone for **10 minutes with no dropout and no popup** — well past
> the ~60 s threshold at which the "unsupported USB microphone" popup used to
> fire. That validates, on real hardware in the real car:
>
> * the TeslaMic descriptor clone works from an RP2040 (the three descriptors the
>   car validates are byte-identical to the real mic — verified over libusb);
> * variable packet sizes are accepted, and this build changes size on *every*
>   frame, ~500x harsher than real clock drift.
>
> **The two-board I2S chain works on the bench**: source board as I2S master ->
> car board as I2S slave -> USB, clean audio, correct bit alignment. Resetting the
> source board cuts audio for about a second and recovers, which is the stall
> detection in `capture` doing its job.
>
> **Not yet tested: the two-board rig in the car.** Bench and car have each been
> proven separately, never together.

## Pairings (flash one image per board)

| Build | Boards | Notes |
|---|---|---|
| **`car-elastic` + `source-adaptive`** | 2x RP2040 | **Recommended.** Source board is I2S master steering itself to the phone's SOF; car board is I2S slave pacing elastically to the car. Bit-exact, no feedback endpoint needed, 48 kHz-only descriptor. Needs Q1 to pass. |
| `car-pcm2706` + a PCM2706 module | 1x RP2040 | Same car binary as `car-elastic`. Fewest unproven parts; no rate control. Needs Q1 to pass. |
| `car-locked` + `source-locked` | 2x RP2040 | Car board is I2S master locked to the car's SOF, fixed 192-byte packets; source board asks the phone to follow via a feedback endpoint. The only option if Q1 fails. |
| `car-STRESS-TEST` | 1x RP2040 | Diagnostic only, see Q1. |

Both designs are built and ready. Which one to ship depends on two facts nobody
knows yet. Each has a firmware build that answers it.

## Q1. Does Tesla accept variable-size isochronous packets?

If yes, the **PCM2706 build** works and is the simpler product (one board, one
firmware, no second USB device to write). If no, only the clock-locked two-board
build can work, because it is the one that emits fixed 192-byte packets.

**Test: `teslamic-rp-car-STRESS-TEST.uf2`** — needs no PCM2706, no source board
and no wiring. It generates a 1 kHz tone internally and deliberately swings the
packet size between 47 and 49 samples on alternate frames, keeping the average
at exactly 48 so nothing else can be blamed. That exercises the variable-packet
mechanism about 500x harder than real drift ever will.

1. Flash it to one RP2040.
2. Plug into the car's data port.
3. Listen.

* **Clean steady 1 kHz tone** -> Tesla tolerates variable packets -> the
  PCM2706 build is safe, and it is the simpler thing to ship.
* **Clicking, warbling, dropouts, or the "unsupported USB microphone" popup**
  -> variable packets are not viable -> the two-board clock-locked build is the
  only correct option.

Note the mic icon should appear either way; this is a test of the *audio*, not
of enumeration.

## Q2. Does the ScreenMate (Android) honour USB audio feedback?

If yes, the two-board chain is fully clock-locked end to end and no sample is
ever dropped or repeated. If no, the source board falls back to a deliberate
sample slip roughly twice a second — inaudible in practice, but not free.

**Test: `teslamic-rp-source.uf2`**, which reports the answer on its own LED.
It needs the car board running as its I2S master to have a clock at all, so:

1. Flash `teslamic-rp-car-locked.uf2` to board A, `teslamic-rp-source.uf2` to
   board B. Wire GPIO2/3/4 between them plus GND (see `bin/car.rs` for pinout).
2. Power board A from the car (or any USB port — it only needs SOF).
3. Plug board B into the ScreenMate and play audio.
4. Watch board B's LED for ~30 s:

| LED | Meaning |
|-----|---|
| **solid** | Feedback honoured. Fully locked chain, zero slips. |
| **double-blink** | Host is ignoring feedback; slipping ~2/s. Still works, slightly lossy. |
| **slow blink** | No I2S clock — board A unpowered, unwired, or its PIO is wrong. |

The LED samples the slip counters over 10 s windows, so give it at least that
long to settle before reading it.

## Deciding

| Q1 variable packets | Q2 feedback | Ship |
|---|---|---|
| OK | either | **PCM2706 build** — one board, simplest to distribute |
| Not OK | honoured | **Two-board locked** — fully locked, no compromises |
| Not OK | ignored | **Two-board locked** — fixed packets to the car, ~2 slips/s at the phone |

Q1 is the one that actually decides the architecture; Q2 only decides how good
the two-board version is. So run Q1 first — if it passes, you may never need the
second board at all.

## I2S bring-up: `teslamic-rp-I2STEST.uf2`

Wire GPIO2 (DATA), GPIO3 (BCK), GPIO4 (LRCK) and **GND** between the two boards,
then flash `teslamic-rp-I2STEST.uf2` to the source-side board and
`teslamic-rp-car-elastic.uf2` to the car-side board, and listen on the car
board's USB input.

The test board drives the link with embassy-rp's **upstream** `PioI2sOut` rather
than any of my PIO code, configured `bit_depth = 32` so BCK is 64x fs — the same
framing `slave_rx` expects and the PCM2706 produces, with the 16-bit sample in
the top half of each word. So this isolates my `slave_rx` against known-good
master code:

| result | meaning |
|---|---|
| clean 997 Hz | wiring and `slave_rx` are both correct |
| distorted / channel-swapped | `slave_rx` bit alignment is wrong (1 bit or 1 slot out) |
| silence | no clock reaching the car board — check wiring, and check GND |

Do this before trusting the two-board pairings. Any fault it shows is in my code,
not upstream's, which is the point.

### Why upstream isn't used in the shipping firmware

`PioI2sIn`/`PioI2sOut` are controller-role only and expose no runtime clock
retuning (their state machine is private). Every pairing here needs a slave on
one side, and both master roles need a steerable clock — that is what adaptive
and clock-locked mean. So they fit as a test master and nowhere else.

## Known issue: the RP2040-Zero status LED

The Zero has no plain LED, only a WS2812 on GPIO16, and the status indicator on
it is **not working**. It shows a boot colour (magenta) and never updates.

What was tried, and what each attempt showed:

1. Status in a spawned task, using embassy-rp's `PioWs2812` (DMA) — LED stayed
   on the boot colour set from `main`.
2. Same, writing unconditionally instead of only on state change — no change, so
   it is not change-detection masking a stable state.
3. Own DMA-free driver pushing the PIO FIFO directly (`src/ws2812.rs`) — no
   change, so it is not the DMA.
4. Driven from the pump loop instead of a task — LED stopped lighting at all.

Attempt 4 is the confusing one and has no explanation I can support. `LoadedProgram`
has no `Drop`, so instruction memory is not being freed underneath it. Parked at
the state that at least shows a boot colour rather than left worse.

**Audio is unaffected by all of this** — the LED is diagnostics only. If it
becomes worth solving, the honest next step is a logic analyser on GPIO16 or RTT
over SWD, not more guessing.

Relevant beyond the LED: attempt 1 suggests spawned tasks may not be getting
polled, and the I2S capture path is also a spawned task doing DMA. Worth keeping
in mind if I2S produces nothing — but note `usb_task` is spawned and works, so it
cannot be a blanket failure.

## Caveat

None of this has run on hardware. The PIO I2S bit alignment is the most likely
thing to be wrong on first power-up; a channel-swapped or distorted signal points
there rather than at anything in this document. `teslamic-rp-car-STRESS-TEST.uf2`
is the exception — it generates audio internally and touches no PIO at all, so it
is the safest first thing to flash.

## Bit-exact end-to-end verification

`tools/bitcompare.py` compares a recording made through the bridge against the
file that was played. It is a far stronger test than listening or than any
status LED, because it proves a negative those cannot: that no sample was lost,
repeated, truncated, reordered, rescaled or mis-framed anywhere between the
source and the recorder.

```sh
tools/bitcompare.py reference.wav recording.wav
tools/bitcompare.py --self-test
```

It aligns the two by correlation, checks that alignment is real, then names what
it finds:

| Result | Means |
|---|---|
| bit-exact | nothing lost, repeated, rescaled or reordered |
| every sample off by 1 LSB | a truncating `int16 -> float -> int16` round-trip; nothing lost |
| N frames missing at a point | a discrete discard, located to the frame |
| repeated frame | a slip down: a starved batch was padded |
| channels swapped **and** one sample skewed | the capture lost frame alignment |
| a constant gain | a volume not at unity — the chain, not the bridge |
| not the same audio | wrong file, or the capture missed it |

The tool self-tests against synthesised versions of every fault it names, so a
result from it means something before it is pointed at real audio.

### Setting up a bit-exact chain

Most failures will be the chain rather than the bridge:

* The source file must **already** be 48 kHz, 16-bit. Anything else is resampled
  or dithered before it reaches us.
* The player needs a bit-perfect path to USB audio, volume at 100%, with every
  effect and normalisation off. On Android, USB Audio Player Pro does this;
  the stock mixer rescales and may drop buffers.
* **Record 32-bit float.** Recording 16-bit adds a truncating conversion that
  leaves ~9% of samples one LSB low. Harmless to listen to, but it hides
  everything else, because with every frame differing an exact comparison
  reports total corruption.

`ffmpeg -f avfoundation` is **not** a usable capture path: measured at about 10%
sustained frame loss (a 5 s capture returned 4.499 s), which destroys sample
alignment while leaving the spectrum intact — so it looks like a bridge fault.
`tools/record-mac.sh` is kept only as a record of that.

## Result: bit-exact, three consecutive cold boots

Android (USB Audio Player Pro, bit-perfect) -> source RP2040 -> I2S -> car
RP2040 -> USB -> Mac, recorded at 32-bit float, compared against the file on the
phone. Three runs with a reset of the car board between each:

```
RUN 1  aligned 1.420 s   2,784,000 frames   PASS bit-exact
RUN 2  aligned 1.990 s   2,784,000 frames   PASS bit-exact
RUN 3  aligned 1.878 s   2,784,000 frames   PASS bit-exact
```

**8,352,000 frames, every one identical.** No loss, no repetition, no drift, no
rescaling, correct channel mapping, correct frame alignment — verifying the
elastic pacing, the I2S framing, the channel order and the clock-domain crossing
together.

Repeating across resets is the point, not thoroughness for its own sake. Frame
alignment used to be decided by the parity of whatever sat in the RX FIFO at
startup, so roughly half of boots were rotated and a single pass proved only
that the coin had landed the right way up. Pushing whole frames removed the
coin. One pass would not have shown that; three across three boots does.

## Earlier single-run result, 2026-09-04

Android (USB Audio Player Pro) -> source RP2040 -> I2S -> car RP2040 -> USB ->
Mac, recorded at 32-bit float, compared against the file on the phone:

```
max fractional error: 0.0
compared 2,784,000 frames (58.0 s)
PASS  bit-exact: every sample matches
```

Every sample arrived identical. No loss, no repetition, no drift, no rescaling,
correct channel mapping, correct frame alignment — which verifies the elastic
pacing, the I2S framing, the channel order and the clock-domain crossing all at
once.

Two firmware faults had to be fixed to reach it, and **neither was visible to
any counter or by ear**: an unprimed pipe was paced as maximum negative drift
and emitted short packets, and the capture could start on the wrong half of a
frame, rotating every sample for the session.

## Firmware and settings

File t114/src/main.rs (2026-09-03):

// SPDX-License-Identifier: MIT
#![no_std]
#![no_main]

//! TeslaMic USB emulator for the Heltec T114 (nRF52840).
//!
//! Goal: make a Tesla show its cabin-microphone ("MIC") overlay icon by
//! enumerating this board as the same USB device the genuine TeslaMic
//! receiver presents.  Based on the descriptor dump from the r/hardwarehacking
//! thread:
//!
//! ```text
//! VID 0x1235  PID 0x0002
//! Manufacturer: "TeslaMic_T004_OTA_231008"
//! Product:      "TeslaMic"
//! Max power:    500 mA
//! IF0  Audio Control
//! IF1  Audio Streaming  (alt0 = idle, alt1 = active)
//!        iso IN endpoint, 192 bytes / 1 ms  =>  48 kHz * 2ch * 16-bit
//! IF2  HID  (interrupt IN, 8 bytes / 1 ms)   [status telemetry]
//! IF3  HID  (control/feature only)           [settings]
//! ```
//!
//! ## What this build does
//!
//! It presents the identity (VID/PID/strings) plus a complete, spec-correct
//! **USB Audio Class 1.0** microphone: an AudioControl interface (microphone
//! input terminal -> USB-streaming output terminal) and an AudioStreaming
//! interface whose active alt-setting advertises 48 kHz / 16-bit / 2-channel
//! PCM over a 192-byte/1 ms isochronous IN endpoint.
//!
//! It also **streams silence**: [`iso_silence_pump`] feeds a 192-byte zero
//! packet per USB frame out the iso endpoint, so to the host this looks like a
//! mic that is actively capturing.  This is done at the register level because
//! embassy-nrf 0.10's USB driver can *allocate* the nRF isochronous endpoint
//! (so it enumerates) but its `EndpointIn::write` asserts `len <= 64` and
//! drives the wrong registers — it cannot push 192-byte iso packets.  The pump
//! carries silence today; the same path carries live samples once an
//! I2S/PDM/SAADC capture fills the buffer.
//!
//! The two HID interfaces from the dump (status telemetry + settings) are
//! omitted for now; if the audio device alone doesn't trigger the icon, add
//! them next.
//!
//! ## Why no SoftDevice
//!
//! The T114 stock image keeps a SoftDevice in flash, but this firmware never
//! calls `sd_softdevice_enable`, so the SD stays dormant and the application
//! owns CLOCK + POWER.  That lets us use embassy-nrf's ordinary USB driver and
//! `HardwareVbusDetect` (VBUS via the POWER peripheral) with no SD plumbing.
//! We force HFXO (external crystal) because the nRF52840 USB peripheral needs
//! the 48 MHz reference derived from it; the internal RC is out of spec for USB.

use embassy_executor::Spawner;
use embassy_nrf::usb::vbus_detect::HardwareVbusDetect;
use embassy_nrf::usb::Driver;
use embassy_nrf::{bind_interrupts, peripherals, usb};
use embassy_usb::descriptor::{SynchronizationType, UsageType};
use embassy_usb::{Builder, Config, UsbVersion};

#[cfg(feature = "stream")]
use embassy_futures::yield_now;
#[cfg(feature = "stream")]
use embassy_nrf::gpio::{Input, Pull};
#[cfg(feature = "stream")]
use embassy_nrf::pac;
#[cfg(feature = "stream")]
use embassy_nrf::pac::usbd::vals::Response;
#[cfg(feature = "stream")]
use embassy_time::Timer;

#[cfg(feature = "hid-heartbeat")]
use embassy_usb::class::hid::{
    Config as HidConfig, HidBootProtocol, HidSubclass, HidWriter, ReportId, RequestHandler,
    State as HidState,
};
#[cfg(feature = "hid-heartbeat")]
use embassy_usb::control::{InResponse, OutResponse, Request, RequestType};
#[cfg(feature = "hid-heartbeat")]
use embassy_usb::Handler;

// ── usb-spy: onboard-TFT USB control-request logger ─────────────────────────
#[cfg(feature = "usb-spy")]
mod st7789;
#[cfg(feature = "usb-spy")]
use core::cell::RefCell;
#[cfg(feature = "usb-spy")]
use core::fmt::Write as _;
#[cfg(feature = "usb-spy")]
use core::sync::atomic::{AtomicU32, Ordering};
#[cfg(feature = "usb-spy")]
use critical_section::Mutex as CsMutex;
#[cfg(feature = "usb-spy")]
use embassy_nrf::gpio::{Level, Output, OutputDrive};
#[cfg(feature = "usb-spy")]
use embassy_nrf::spim::{self, Spim};
#[cfg(feature = "usb-spy")]
use embassy_time::Delay;
// (Handler / Request / InResponse / RequestType come from the hid-heartbeat
// imports above — usb-spy implies hid-heartbeat.)
#[cfg(feature = "usb-spy")]
use embassy_usb::control::Recipient;
#[cfg(feature = "usb-spy")]
use embassy_usb::driver::Direction;
#[cfg(feature = "usb-spy")]
use embassy_usb::types::InterfaceNumber;
#[cfg(feature = "usb-spy")]
use embedded_graphics::{
    mono_font::{ascii::FONT_5X8, MonoTextStyle},
    pixelcolor::Rgb565,
    prelude::*,
    text::Text,
};
#[cfg(feature = "usb-spy")]
use heapless::{Deque, String, Vec};
#[cfg(feature = "usb-spy")]
use st7789::{Framebuffer, St7789};

// SPIM interrupt for the display bus (TWISPI1). Separate bind so it only exists
// in the usb-spy build.
#[cfg(feature = "usb-spy")]
embassy_nrf::bind_interrupts!(struct SpiIrqs {
    TWISPI1 => spim::InterruptHandler<embassy_nrf::peripherals::TWISPI1>;
});

// Audio format, parameterized at build time by build.rs from
// TESLAMIC_RATE / TESLAMIC_CHANNELS / TESLAMIC_BITS (defaults 48000 / 2 / 16).
// Brings in: SAMPLE_RATE, CHANNELS, BITS, BYTES_PER_SAMPLE,
//            MAX_SAMPLES_PER_FRAME, MAX_BYTES_PER_FRAME.
include!(concat!(env!("OUT_DIR"), "/format.rs"));

// wMaxPacketSize for the iso IN endpoint.
//
// The packet-stress diagnostics sometimes send 49 samples, so their endpoint
// must advertise room for one extra frame. That deviates from the real mic's
// 192, which is exactly why `packet-stress-control` exists: it carries the same
// 196 with a *constant* 48 samples, so the two builds together separate "the car
// dislikes varying packet sizes" from "the car dislikes wMaxPacketSize != 192".
#[cfg(any(
    feature = "packet-stress",
    feature = "packet-stress-control",
    feature = "packet-stress-gentle"
))]
const EP_MAX_BYTES: usize = MAX_BYTES_PER_FRAME + CHANNELS * BYTES_PER_SAMPLE;
#[cfg(not(any(
    feature = "packet-stress",
    feature = "packet-stress-control",
    feature = "packet-stress-gentle"
)))]
const EP_MAX_BYTES: usize = MAX_BYTES_PER_FRAME;

// Minimal panic handler: no probe is attached in the car, so there is nothing
// to print to — just idle the core.  (Avoids pulling in defmt / panic-probe.)
#[panic_handler]
fn panic(_info: &core::panic::PanicInfo) -> ! {
    loop {
        cortex_m::asm::wfi();
    }
}

bind_interrupts!(struct Irqs {
    USBD => usb::InterruptHandler<peripherals::USBD>;
    // POWER/CLOCK IRQ drives HardwareVbusDetect (USB-detected / removed /
    // power-ready events).  Available to us because the SoftDevice is dormant.
    CLOCK_POWER => usb::vbus_detect::InterruptHandler;
});

// ── USB Audio Class 1.0 descriptor constants ────────────────────────────────
// (Values from the USB Device Class Definition for Audio Devices, rel. 1.0.)

const CS_INTERFACE: u8 = 0x24;
const CS_ENDPOINT: u8 = 0x25;

// Interface class/subclass codes.
const AUDIO_CLASS: u8 = 0x01;
const SUBCLASS_AUDIOCONTROL: u8 = 0x01;
const SUBCLASS_AUDIOSTREAMING: u8 = 0x02;
const PROTO_UNDEFINED: u8 = 0x00;

// AudioControl class-specific descriptors (payloads start at bDescriptorSubtype;
// embassy prepends bLength + bDescriptorType).
//
// AC interface header: bcdADC 1.00, wTotalLength = 9+12+9 = 30 (0x001E),
// 1 streaming interface in the collection: interface #1.
const AC_HEADER: [u8; 7] = [
    0x01, // HEADER
    0x00, 0x01, // bcdADC = 0x0100
    0x1E, 0x00, // wTotalLength = 30
    0x01, // bInCollection = 1
    0x01, // baInterfaceNr(1) = interface 1 (AudioStreaming)
];

// Input Terminal: ID 1, type 0x0201 (Microphone), CHANNELS channels.
// 12 bytes total once embassy prepends bLength (0x0C) + bDescriptorType.
const AC_INPUT_TERMINAL: [u8; 10] = [
    0x02, // INPUT_TERMINAL
    0x01, // bTerminalID = 1
    0x01, 0x02, // wTerminalType = 0x0201 (Microphone)
    0x00, // bAssocTerminal
    CHANNELS as u8, // bNrChannels
    (CHANNEL_MASK & 0xff) as u8,
    (CHANNEL_MASK >> 8) as u8, // wChannelConfig
    0x00, // iChannelNames
    0x00, // iTerminal
];

// Output Terminal: ID 2, type 0x0101 (USB Streaming), sourced from terminal 1.
const AC_OUTPUT_TERMINAL: [u8; 7] = [
    0x03, // OUTPUT_TERMINAL
    0x02, // bTerminalID = 2
    0x01, 0x01, // wTerminalType = 0x0101 (USB Streaming)
    0x00, // bAssocTerminal
    0x01, // bSourceID = 1 (the microphone input terminal)
    0x00, // iTerminal
];

// AudioStreaming (alt 1) class-specific general descriptor:
// links to terminal 2, 1 ms delay, PCM format tag (0x0001).
const AS_GENERAL: [u8; 5] = [
    0x01, // AS_GENERAL
    0x02, // bTerminalLink = 2 (USB streaming output terminal)
    0x01, // bDelay = 1 frame
    0x01, 0x00, // wFormatTag = 0x0001 (PCM)
];

// Format Type I: CHANNELS channels, BYTES_PER_SAMPLE bytes/subframe, BITS
// resolution, one discrete sample rate = SAMPLE_RATE (little-endian 3-byte).
const AS_FORMAT_TYPE_I: [u8; 9] = [
    0x02, // FORMAT_TYPE
    0x01, // bFormatType = FORMAT_TYPE_I
    CHANNELS as u8,         // bNrChannels
    BYTES_PER_SAMPLE as u8, // bSubframeSize
    BITS,                   // bBitResolution
    0x01,                   // bSamFreqType = 1 discrete frequency
    (SAMPLE_RATE & 0xff) as u8,
    ((SAMPLE_RATE >> 8) & 0xff) as u8,
    ((SAMPLE_RATE >> 16) & 0xff) as u8,
];

// Class-specific AS isochronous audio-data endpoint descriptor.
const AS_ISO_ENDPOINT: [u8; 5] = [
    0x01, // EP_GENERAL
    0x00, // bmAttributes (no sampling-freq / pitch control)
    0x00, // bLockDelayUnits
    0x00, 0x00, // wLockDelay
];

// Minimal vendor-defined HID report descriptor: one 8-byte input report.
// The genuine TeslaMic's real report layout is unknown (not in the dump), so
// this just makes IF2 a valid HID device that can push 8-byte reports; the
// heartbeat content is a separate guess (see the heartbeat loop in `main`).
// ── Real TeslaMic HID descriptors (dumped from a clone — see real_mic_dump.md) ─
// IF2 is a standard HID boot keyboard (the mic's physical button -> keystrokes).
#[cfg(feature = "hid-heartbeat")]
#[rustfmt::skip]
const HID_REPORT_KEYBOARD: [u8; 65] = [
    0x05, 0x01, 0x09, 0x06, 0xa1, 0x01, 0x05, 0x07, 0x19, 0xe0, 0x29, 0xe7,
    0x15, 0x00, 0x25, 0x01, 0x75, 0x01, 0x95, 0x08, 0x81, 0x02, 0x95, 0x01,
    0x75, 0x08, 0x81, 0x01, 0x95, 0x05, 0x75, 0x01, 0x05, 0x08, 0x19, 0x01,
    0x29, 0x05, 0x91, 0x02, 0x95, 0x01, 0x75, 0x03, 0x91, 0x01, 0x95, 0x06,
    0x75, 0x08, 0x15, 0x00, 0x26, 0xa4, 0x00, 0x05, 0x07, 0x19, 0x00, 0x2a,
    0xa4, 0x00, 0x81, 0x00, 0xc0,
];

// IF3 is an endpoint-less vendor HID (Usage Page 0xFF00, Usage 0x55AA) with a
// 256-B Input, 256-B Output and 8-B Feature report (report ID 0). The car writes
// its A5 5A config to the Output report via SET_REPORT.
#[cfg(feature = "hid-heartbeat")]
#[rustfmt::skip]
const HID_REPORT_IF3: [u8; 36] = [
    0x06, 0x00, 0xff, 0x0a, 0xaa, 0x55, 0xa1, 0x01, 0x15, 0x00, 0x26, 0xff,
    0x00, 0x75, 0x08, 0x96, 0x00, 0x01, 0x09, 0x01, 0x81, 0x02, 0x96, 0x00,
    0x01, 0x09, 0x01, 0x91, 0x02, 0x95, 0x08, 0x09, 0x01, 0xb1, 0x02, 0xc0,
];

// IF3's 9-byte HID descriptor (bcdHID 2.01, one 36-byte report descriptor).
#[cfg(feature = "hid-heartbeat")]
const HID_DESC_IF3: [u8; 9] = [0x09, 0x21, 0x01, 0x02, 0x00, 0x01, 0x22, 0x24, 0x00];

// IF3 Feature report the real mic returns on GET_REPORT(Feature) — version/status.
#[cfg(feature = "hid-heartbeat")]
const IF3_FEATURE: [u8; 8] = [0x00, 0x01, 0x00, 0x03, 0x03, 0x00, 0x08, 0x00];

// IF2 keyboard request handler: return the empty key state on GET_REPORT.
#[cfg(feature = "hid-heartbeat")]
struct KeyboardHandler;
#[cfg(feature = "hid-heartbeat")]
impl RequestHandler for KeyboardHandler {
    fn get_report(&mut self, _id: ReportId, buf: &mut [u8]) -> Option<usize> {
        let n = buf.len().min(8);
        buf[..n].fill(0);
        Some(n)
    }
    fn set_report(&mut self, _id: ReportId, _data: &[u8]) -> OutResponse {
        OutResponse::Accepted
    }
    fn get_idle_ms(&mut self, _id: Option<ReportId>) -> Option<u32> {
        Some(0)
    }
}

// IF3 is endpoint-less, so embassy's HidWriter can't build it. We hand-roll a
// Handler that serves its report/HID descriptor, returns the Feature report, and
// accepts the car's SET_REPORT config writes — exactly what the real mic does.
#[cfg(feature = "hid-heartbeat")]
struct If3Handler;
#[cfg(feature = "hid-heartbeat")]
impl Handler for If3Handler {
    fn control_in<'a>(&'a mut self, req: Request, buf: &'a mut [u8]) -> Option<InResponse<'a>> {
        if req.index != 3 {
            return None;
        }
        match (req.request_type, req.request) {
            // Standard GET_DESCRIPTOR: report (0x22) or HID (0x21) descriptor.
            (RequestType::Standard, 0x06) => match (req.value >> 8) as u8 {
                0x22 => Some(InResponse::Accepted(&HID_REPORT_IF3)),
                0x21 => Some(InResponse::Accepted(&HID_DESC_IF3)),
                _ => Some(InResponse::Rejected),
            },
            // Class GET_REPORT: return the Feature report.
            (RequestType::Class, 0x01) => {
                let n = IF3_FEATURE.len().min(buf.len());
                buf[..n].copy_from_slice(&IF3_FEATURE[..n]);
                Some(InResponse::Accepted(&buf[..n]))
            }
            _ => None,
        }
    }
    fn control_out(&mut self, req: Request, _data: &[u8]) -> Option<OutResponse> {
        if req.index != 3 {
            return None;
        }
        // Accept the car's SET_REPORT (config writes) and SET_IDLE.
        match req.request_type {
            RequestType::Class => Some(OutResponse::Accepted),
            _ => None,
        }
    }
}
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
async fn main(spawner: Spawner) {
    // Force HFXO: USB needs the crystal-derived 48 MHz reference.  Legal to set
    // here because the SoftDevice is dormant and we own the CLOCK peripheral.
    let mut nrf_config = embassy_nrf::config::Config::default();
    nrf_config.hfclk_source = embassy_nrf::config::HfclkSource::ExternalXtal;
    let p = embassy_nrf::init(nrf_config);

    // USB driver + hardware VBUS detection (POWER peripheral).
    let vbus = HardwareVbusDetect::new(Irqs);
    let driver = Driver::new(p.USBD, Irqs, vbus);

    // ── Device identity: clone the TeslaMic (strings + serial from real_mic_dump) ─
    let mut config = Config::new(0x1235, 0x0002);
    config.manufacturer = Some("TeslaMic_V004_FW_20220217Tes");
    config.product = Some("TeslaMic");
    // The real mic exposes a 40-byte serial (per-session random); the car reads it.
    config.serial_number =
        Some("0E02070008181F0B8AFB76F93A8C1B1D472AA0AA0C2535898B4D6A4738FAD0057B6A12DB17320B75");
    config.bcd_usb = UsbVersion::Two; // real mic is 0x0110; enum lacks it, 0x0200 is harmless
    config.max_power = 500; // mA, matches the dump
    config.self_powered = false;
    // Plain (non-IAD) composite device: class codes live on the interfaces.
    config.composite_with_iads = false;
    config.device_class = 0x00;
    config.device_sub_class = 0x00;
    config.device_protocol = 0x00;
    config.max_packet_size_0 = 64;

    // HID state + handlers — declared before the builder/buffers so they outlive
    // `usb` (which holds handlers that borrow them).
    #[cfg(feature = "hid-heartbeat")]
    let mut hid_state = HidState::new(); // IF2 keyboard
    #[cfg(feature = "hid-heartbeat")]
    let mut kbd_handler = KeyboardHandler;
    #[cfg(feature = "hid-heartbeat")]
    let mut if3_handler = If3Handler; // IF3 endpoint-less vendor HID
    #[cfg(feature = "usb-spy")]
    let mut spy = SpyHandler;

    // Descriptor / control buffers.  Live on main's stack; main never returns
    // (usb.run() loops forever) so they outlive every use.
    let mut config_descriptor = [0u8; 256];
    let mut bos_descriptor = [0u8; 32];
    let mut msos_descriptor = [0u8; 16];
    // Must hold the largest control-transfer payload — the 40-byte serial string
    // descriptor is 2 + 80*2 = 162 bytes, so 128 was too small (broke enumeration).
    let mut control_buf = [0u8; 512];

    let mut builder = Builder::new(
        driver,
        config,
        &mut config_descriptor,
        &mut bos_descriptor,
        &mut msos_descriptor,
        &mut control_buf,
    );

    // ── Build the Audio function (IF0 = control, IF1 = streaming) ──────────
    let mut func = builder.function(AUDIO_CLASS, SUBCLASS_AUDIOCONTROL, PROTO_UNDEFINED);

    // IF0: AudioControl (topology only, no endpoints).
    {
        let mut ac = func.interface();
        let mut alt = ac.alt_setting(AUDIO_CLASS, SUBCLASS_AUDIOCONTROL, PROTO_UNDEFINED, None);
        alt.descriptor(CS_INTERFACE, &AC_HEADER);
        alt.descriptor(CS_INTERFACE, &AC_INPUT_TERMINAL);
        alt.descriptor(CS_INTERFACE, &AC_OUTPUT_TERMINAL);
    }

    // IF1: AudioStreaming.
    {
        let mut stream = func.interface();
        // alt 0 — zero-bandwidth idle setting (no endpoints).
        stream.alt_setting(AUDIO_CLASS, SUBCLASS_AUDIOSTREAMING, PROTO_UNDEFINED, None);
        // alt 1 — active setting with the isochronous IN endpoint.
        let mut alt1 =
            stream.alt_setting(AUDIO_CLASS, SUBCLASS_AUDIOSTREAMING, PROTO_UNDEFINED, None);
        alt1.descriptor(CS_INTERFACE, &AS_GENERAL);
        alt1.descriptor(CS_INTERFACE, &AS_FORMAT_TYPE_I);
        // Iso IN, 1 ms interval, wMaxPacketSize = the largest frame this format
        // needs (ceil(rate/1000) * channels * bytes).  On the nRF this lands on
        // EP8 (0x88); the exact number doesn't match the genuine 0x84 but hosts
        // key on the class/format, not the address.  extra_fields = [bRefresh,
        // bSynchAddress] makes this the 9-byte UAC audio-endpoint form.
        let _iso_in = alt1.endpoint_isochronous_in(
            None,
            EP_MAX_BYTES as u16,
            1,
            SynchronizationType::Asynchronous,
            UsageType::DataEndpoint,
            &[0x00, 0x00],
        );
        // Class-specific AS iso endpoint descriptor follows the standard one.
        alt1.descriptor(CS_ENDPOINT, &AS_ISO_ENDPOINT);
    }

    drop(func);

    // Register the spy FIRST so it observes every delegated control request
    // before the HID class handler (added next) answers it.
    #[cfg(feature = "usb-spy")]
    builder.handler(&mut spy);

    // IF2: HID keyboard (real mic's report descriptor). Interrupt IN endpoint;
    // we never send keystrokes (no keys pressed), matching an idle mic button.
    // Kept alive so the endpoint stays allocated; its reports are never written.
    #[cfg(feature = "hid-heartbeat")]
    let _hid_kbd: HidWriter<'_, _, 8> = HidWriter::new(
        &mut builder,
        &mut hid_state,
        HidConfig {
            report_descriptor: &HID_REPORT_KEYBOARD,
            request_handler: Some(&mut kbd_handler),
            poll_ms: 1,
            max_packet_size: 8,
            hid_subclass: HidSubclass::No,
            hid_boot_protocol: HidBootProtocol::None,
        },
    );

    // IF3: endpoint-less vendor HID. embassy's HidWriter always allocates an
    // endpoint, so we hand-roll the interface (HID class, one alt, HID descriptor,
    // no endpoint) and let `If3Handler` serve its report/feature and accept writes.
    #[cfg(feature = "hid-heartbeat")]
    {
        let mut func3 = builder.function(0x03, 0x00, 0x00);
        let mut iface3 = func3.interface();
        let mut alt3 = iface3.alt_setting(0x03, 0x00, 0x00, None);
        // 0x21 = HID descriptor; payload is the bytes after bLength + type.
        alt3.descriptor(0x21, &HID_DESC_IF3[2..]);
        // (no endpoint)
    }
    #[cfg(feature = "hid-heartbeat")]
    builder.handler(&mut if3_handler);

    let mut usb = builder.build();

    // Feed the isochronous IN endpoint at the register level.  embassy-nrf's
    // driver can't write the iso endpoint (see module docs), so this task
    // drives USBD.ISOIN directly.  It waits until the host activates
    // AudioStreaming alt-1 before sending anything.
    //
    // The user button (P1_10, active-low) only matters in the `sine-button`
    // build; we configure it unconditionally (harmless) so one task serves all
    // stream variants.  Task macro returns a Result; Err only if the pool is
    // already occupied, impossible on first spawn.
    #[cfg(feature = "stream")]
    {
        let button = Input::new(p.P1_10, Pull::Up);
        spawner.spawn(iso_pump(button).unwrap());
    }
    #[cfg(not(feature = "stream"))]
    let _ = &spawner;

    // Bring up the onboard ST7789 TFT and stream the spy log to it.
    #[cfg(feature = "usb-spy")]
    {
        let mut spicfg = spim::Config::default();
        spicfg.frequency = spim::Frequency::M8;
        spicfg.mode = spim::MODE_0;
        let dspi = Spim::new_txonly(p.TWISPI1, SpiIrqs, p.P1_08, p.P1_09, spicfg);
        // nRF52840 SPIM-SCK PIN_CNF fixup for P1.08 (see wireless-performer-fw):
        // force PIN_CNF[8].INPUT so SCK toggles correctly.
        unsafe {
            core::ptr::write_volatile(0x5000_0A20 as *mut u32, 0x301);
        }
        let cs = Output::new(p.P0_11, Level::High, OutputDrive::HighDrive);
        let dc = Output::new(p.P0_12, Level::Low, OutputDrive::HighDrive);
        let rst = Output::new(p.P0_02, Level::High, OutputDrive::HighDrive);
        let vtft = Output::new(p.P0_03, Level::High, OutputDrive::Standard); // active-low gate
        let backlight = Output::new(p.P0_15, Level::High, OutputDrive::Standard); // active-low
        let disp = St7789::new(dspi, cs, dc, rst, vtft, Delay);
        spawner.spawn(display_task(disp, backlight).unwrap());
    }

    // Run the device: handles enumeration + all control transfers forever
    // (including the IF3 config writes, answered by If3Handler). IF2 is a keyboard
    // that never presses a key, so there's nothing to stream from the app side.
    usb.run().await;
}
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

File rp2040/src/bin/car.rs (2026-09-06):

// SPDX-License-Identifier: MIT
#![no_std]
#![no_main]

//! Car-facing board: presents the TeslaMic to the Tesla and streams whatever
//! arrives on I2S.
//!
//! Two builds from one source:
//!
//! * **default** — I2S *slave*. Pair with a PCM2706 module: the phone plugs into
//!   the PCM2706, which is the I2S master with its clock PLL'd off the phone's
//!   USB SOF. Our clock and the car's are then independent, so the pipe runs in
//!   [`PaceMode::Elastic`] and the iso packet size varies by +/-1 sample to
//!   absorb drift. One board, no second firmware.
//!
//! * **`--features clock-locked`** — I2S *master*, with the clock divider
//!   trimmed continuously so exactly 48 audio frames elapse per USB SOF. The
//!   source board is the I2S slave, so the entire chain ends up running on the
//!   car's clock, there is no drift, and every iso packet is exactly 192 bytes —
//!   matching the real TeslaMic's fixed-size adaptive endpoint. Requires the
//!   `source` binary on a second board.
//!
//! Pins (must be consecutive — see `i2s_pio`): GPIO2 DATA, GPIO3 BCK, GPIO4 LRCK.
//! Status LED on GPIO25.

use embassy_executor::Spawner;
use embassy_rp::bind_interrupts;
#[cfg(not(feature = "rp2040-zero"))]
use embassy_rp::gpio::{Level, Output};
use embassy_rp::peripherals::{PIO0, USB};
use embassy_rp::pio::{InterruptHandler as PioInterruptHandler, Pio};
use embassy_rp::usb::{Driver, InterruptHandler as UsbInterruptHandler};
use embassy_sync::blocking_mutex::raw::CriticalSectionRawMutex;
use embassy_sync::blocking_mutex::Mutex;
use embassy_time::{Duration, Instant};
use embassy_usb::class::hid::State as HidState;
use embassy_usb::driver::{EndpointError, EndpointIn};
use embassy_usb::Builder;

use core::cell::RefCell;

#[path = "../audio_pipe.rs"]
mod audio_pipe;
#[path = "../i2s_pio.rs"]
mod i2s_pio;
#[macro_use]
#[path = "../pins.rs"]
mod pins;
#[path = "../status.rs"]
mod status;
#[path = "../ws2812.rs"]
mod ws2812;
#[path = "../teslamic.rs"]
mod teslamic;

use audio_pipe::{classify, PaceMode, Pipe, RateDetect};

/// ~10 ms of slack at 48 kHz, half in each direction. Comfortably larger than
/// the I2S DMA block so burst delivery never trips the pacer (see the deadband
/// note in `audio_pipe`).
#[cfg(not(feature = "low-latency"))]
const RING: usize = 512;
/// Half the cushion. Target 128 must exceed deadband (64) + producer burst (16)
/// = 80, leaving 48 frames of margin.
#[cfg(feature = "low-latency")]
const RING: usize = 256;
/// Deadband. Must exceed the larger of the two burst sizes: the I2S DMA block
/// coming in, and one USB frame going out.
#[cfg(not(feature = "low-latency"))]
const HYSTERESIS: usize = 96;
#[cfg(feature = "low-latency")]
const HYSTERESIS: usize = 64;

/// Frames per I2S DMA block. Must stay under the pipe's deadband (96 frames at
/// 48 kHz) or the pacer chases its own sampling phase.
#[cfg(not(feature = "low-latency"))]
const I2S_BLOCK: usize = 64;
/// Smaller blocks mean a smaller producer burst, which is what lets the cushion
/// shrink. Costs more frequent DMA completions, which the RP2040 absorbs easily.
#[cfg(feature = "low-latency")]
const I2S_BLOCK: usize = 16;

#[cfg(all(not(feature = "clock-locked"), not(feature = "packet-stress")))]
const MODE: PaceMode = PaceMode::Elastic;
#[cfg(all(feature = "clock-locked", not(feature = "packet-stress")))]
const MODE: PaceMode = PaceMode::Locked;
#[cfg(feature = "packet-stress")]
const MODE: PaceMode = PaceMode::Stress;

/// 256-point sine, quarter scale. Used by the `packet-stress` and `pipe-tone`
/// diagnostics.
///
/// Indexed by a phase accumulator at **997 Hz**, not 1000 Hz, and interpolated.
/// Both details matter: 1 kHz at 48 kHz is exactly 48 samples, i.e. exactly one
/// cycle per USB packet, so a fault that merely reorders a packet's contents is
/// completely inaudible — that blind spot hid a real corruption bug in the nRF
/// firmware for two months. 997 shares no factor with the frame rate. And
/// indexing by the top 8 bits alone gives only ~-40 dBFS of phase-truncation
/// error, audible as a spurious tone, so the low bits interpolate.
#[cfg(any(feature = "packet-stress", feature = "pipe-tone"))]
#[rustfmt::skip]
const SINE256: [i16; 256] = [
         0,    393,    785,   1177,   1568,   1959,   2348,   2735,
      3121,   3506,   3888,   4267,   4645,   5019,   5390,   5758,
      6123,   6484,   6841,   7194,   7542,   7886,   8226,   8560,
      8889,   9213,   9531,   9844,  10150,  10451,  10745,  11033,
     11314,  11588,  11855,  12115,  12368,  12614,  12851,  13081,
     13304,  13518,  13724,  13921,  14111,  14292,  14464,  14627,
     14782,  14928,  15065,  15192,  15311,  15420,  15521,  15611,
     15693,  15764,  15827,  15880,  15923,  15957,  15981,  15995,
     16000,  15995,  15981,  15957,  15923,  15880,  15827,  15764,
     15693,  15611,  15521,  15420,  15311,  15192,  15065,  14928,
     14782,  14627,  14464,  14292,  14111,  13921,  13724,  13518,
     13304,  13081,  12851,  12614,  12368,  12115,  11855,  11588,
     11314,  11033,  10745,  10451,  10150,   9844,   9531,   9213,
      8889,   8560,   8226,   7886,   7542,   7194,   6841,   6484,
      6123,   5758,   5390,   5019,   4645,   4267,   3888,   3506,
      3121,   2735,   2348,   1959,   1568,   1177,    785,    393,
         0,   -393,   -785,  -1177,  -1568,  -1959,  -2348,  -2735,
     -3121,  -3506,  -3888,  -4267,  -4645,  -5019,  -5390,  -5758,
     -6123,  -6484,  -6841,  -7194,  -7542,  -7886,  -8226,  -8560,
     -8889,  -9213,  -9531,  -9844, -10150, -10451, -10745, -11033,
    -11314, -11588, -11855, -12115, -12368, -12614, -12851, -13081,
    -13304, -13518, -13724, -13921, -14111, -14292, -14464, -14627,
    -14782, -14928, -15065, -15192, -15311, -15420, -15521, -15611,
    -15693, -15764, -15827, -15880, -15923, -15957, -15981, -15995,
    -16000, -15995, -15981, -15957, -15923, -15880, -15827, -15764,
    -15693, -15611, -15521, -15420, -15311, -15192, -15065, -14928,
    -14782, -14627, -14464, -14292, -14111, -13921, -13724, -13518,
    -13304, -13081, -12851, -12614, -12368, -12115, -11855, -11588,
    -11314, -11033, -10745, -10451, -10150,  -9844,  -9531,  -9213,
     -8889,  -8560,  -8226,  -7886,  -7542,  -7194,  -6841,  -6484,
     -6123,  -5758,  -5390,  -5019,  -4645,  -4267,  -3888,  -3506,
     -3121,  -2735,  -2348,  -1959,  -1568,  -1177,   -785,   -393,
];

/// Phase step per sample for the diagnostic tone.
#[cfg(any(feature = "packet-stress", feature = "pipe-tone"))]
const TONE_PHASE_INC: u32 = ((997u64 << 32) / 48_000u64) as u32;
/// Default advertised rate. The board follows the source instead of insisting on
/// this — see `boot_rate` and the renegotiation in `pump`.
const DEFAULT_RATE: u32 = teslamic::SAMPLE_RATE;
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

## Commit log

2026-07-12 Add IF3, USB control-request spy (onboard TFT), and RESEARCH.md
    - Add second HID interface (IF3) to match the genuine TeslaMic's 4-interface
    tree; answer HID GET_REPORT/SET_REPORT instead of STALL.
    - New usb-spy build: logs every USB control request to the onboard ST7789 TFT,
    turning the T114 into its own USB analyzer (ported st7789 driver +
    framebuffer from wireless-performer-fw, AGPL header retained).
    - Spy decoded the car's connect handshake + the A5 5A config protocol it writes
    to IF3; confirmed the accept/reject check is on the interrupt-IN side we can't
    see -> needs a real mic + sniffer.
    - RESEARCH.md: full findings, captured byte sequences, and the mic+sniffer plan.
    - Also: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
    [framebuffer.rs, main.rs, st7789.rs]
2026-07-14 Match real TeslaMic descriptors (dumped from a clone)
    Dumped a working clone via libusb (see real_mic_dump.md) and rewrote the HID
    emulation to match byte-for-byte:
    - IF2 is a real HID keyboard (65-byte report descriptor), not a vendor blob.
    - IF3 is endpoint-less vendor HID (Usage 0x55AA, 256B In/Out + 8B Feature),
    hand-rolled with an If3Handler that serves its descriptor + the Feature report
    0001000303000800 and accepts the car's A5 5A SET_REPORT config writes.
    - Added the 40-byte serial + clone manufacturer string; bumped control_buf to
    512 so the long serial string descriptor doesn't break enumeration.
    Verified on macOS: IF2/IF3 report descriptors and IF3 Feature report all match
    t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
    [main.rs]
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2026-09-02 Add `ramp` diagnostic build to trace the 44.1 kHz buzz
    teslamic-44k.uf2 buzzes on macOS as well as in the car, so the fault is in this
    firmware rather than the car's resampling as RESEARCH.md assumed. The
    fractional-rate accumulator is arithmetically correct (nine 44-sample frames
    then one 45 = 441 per 10 ms, exactly 44100/s), so the bug is elsewhere. The
    packet size changes every 10th frame, i.e. at 100 Hz, which fits the symptom.
    Note this cannot be isolated by choosing another rate: for every standard rate,
    "fractional samples per frame" and "44.1 kHz family" are the same set.
    `--features ramp` therefore replaces the audio payload with a 16-bit counter
    that increments once per sample, a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
    [main.rs]
2026-09-02 Add RP2040 firmware for the real-audio front end
    The car and the audio source are both USB hosts, so the bridge has to be a USB
    device on two links at once. The nRF52840 has one device-only USB peripheral
    and cannot, so this adds an RP2040 crate: `source` faces the phone as a UAC1
    speaker, `car` faces the Tesla as the TeslaMic, and audio crosses between them
    over I2S.
    - src/audio_pipe.rs: the clock-domain bridge both boards share. Ring buffer,
    drift pacing and source rate detection, with no HAL dependency so it runs
    under 23 host unit tests. Its deadband must exceed the producer's I2S burst
    size; a narrower one corrected 16 times a minute at zero drift.
    - rp2040/src/teslamic.rs: the d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
    [car.rs, source.rs]
2026-09-03 Fix ISO IN corruption, and add the diagnostics that found it
    Two independent bugs were corrupting every isochronous packet this firmware has
    ever sent.
    1. A DMA race. The pump detected SOF and then generated a whole frame of samples
    before calling arm_iso, but hosts issue the isochronous IN token within
    microseconds of SOF. The host routinely read the endpoint buffer while EasyDMA
    was still filling it and got a mixture: the 64-byte chunks already written held
    the new frame, the rest still held the previous one. Recorded against the ramp
    counter, each 192-byte packet arrived rotated at a 64-byte boundary with the
    stale chunks reading exactly one frame (48 samples) behind.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
    [main.rs]
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2026-09-03 Fix the same test-tone blind spot in the RP2040 stress build
    car.rs generated its packet-stress tone from a 48-entry table at 48 kHz — exactly
    1 kHz, exactly one cycle per USB packet. That is precisely the blind spot that
    hid the ISO corruption in the nRF firmware for two months, so this build could
    have reported a corrupted stream as clean.
    Now a 997 Hz phase accumulator against a 256-point table, interpolated, matching
    the nRF firmware.
    [car.rs]
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2026-09-03 Fix three RP2040 faults found on first hardware bring-up
    All three were found by running the board, not by reading the code.
    1. The pump gated every write on the USB frame counter (SOF_RD) changing, but
    embassy-rp never enables SOF tracking — there is no reference to dev_sof or
    sof_rd anywhere in its USB driver, so the register need not advance. The loop
    spun without ever sending a packet: the device enumerated correctly and then
    hung any host that opened the stream. The gate was redundant anyway, since
    write().await already returns exactly once per frame; that IS the pacing.
    Both boards now derive a USB_FRAMES counter from completed transfers, which
    the clock-locked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
    [car.rs, source.rs]
2026-09-03 Support the RP2040-Zero: WS2812 status, and keep PIO Common alive
    The Zero has no plain LED. Its only indicator is a WS2812 on GPIO16, so
    --features rp2040-zero (now the default in build-uf2.sh) drives colour over PIO1
    instead of blinking GPIO25: green streaming, blue waiting, red fault, amber
    slipping. status.rs abstracts the two so the binaries don't care which board
    they are on.
    The LED then didn't work, and the reason is worth recording because it is a trap
    for any PIO peripheral, not just this one. embassy-rp's `Drop for Common` calls
    on_pio_drop(), which resets every PIO-claimed pin's function-select to NULL once
    the user count falls to 1. Building the LED inside a `let led = { ... }`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
    [status.rs]
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2026-09-03 Fix the rate check muting perfectly good audio
    The car board streamed silence over I2S even though the samples were arriving
    correctly. Two separate `RateDetect` instances were to blame: the capture task
    fed one with `on_capture()` and the pump ticked the other with `on_usb_frame()`,
    so the pump's detector saw zero captured frames per second, computed 0 Hz, failed
    `classify()`, and latched MUTED exactly one second after boot. The guard meant to
    protect against a wrong-pitch source was zeroing the audio instead.
    Rate detection needs both halves and they live in different tasks, so the frame
    count now crosses between them through a `CAPTURED` atomic and the detector lives
    only in the pump.
    A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
    [car.rs]
2026-09-03 Add isolation binaries for PIO and I2S bring-up
    Each answers exactly one question with nothing else in the path. Chasing the
    same symptom by reasoning cost several flash cycles; these took minutes each and
    gave unambiguous answers.
    - ledtest - WS2812 only. Proved the LED driver, PIO program, clock divider and
    pin were all correct, so the fault was an interaction.
    - i2ssniff - GPIO3/GPIO4 as plain GPIO inputs, counting edges. Proves whether a
    clock is arriving at all, with no PIO involved, and incidentally
    whether the source board is running (it has no LED and does not
    enumerate).
    - i2srx - the real `slave_rx` plus DMA, reporting stalle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
    [i2ssniff.rs, i2stest.rs]
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2026-09-03 Source board: upstream I2S master, and an exactly-48 kHz system clock
    Two changes, both to get real audio from a host through to the car board.
    Use embassy-rp's upstream PioI2sOut rather than my own master_tx. i2srx proved
    my slave_rx against upstream's master; master_tx has still never run on hardware
    and had a bit-clock-ratio bug as recently as yesterday, so there was no reason to
    prefer it. bit_depth = 32 puts BCK at 64x fs, the framing slave_rx expects and
    the PCM2706 produces, with the 16-bit sample in the top half of each word.
    The cost is that upstream exposes no runtime clock retuning, so this board runs
    on its own clock rather than steering to the host, and Pipe::slip absorbs the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
    [source.rs]
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2026-09-03 Retune the source buffer for host bursts, and stop pacing when paused
    Two issues seen with an iPhone source.
    Amber whenever music was paused. A paused host stops delivering while the
    endpoint stays enabled, so the buffer ran dry and the pacer kept trying to
    correct a buffer with nothing in it — a slip storm for as long as the pause
    lasted. `Pipe::starved()` distinguishes "the source has stopped" from "we have
    drifted", and the source board now re-arms instead of pacing, so a pause reads as
    waiting rather than as a fault.
    Amber intermittently during playback. The deadband was two USB frames (96), but
    hosts bunch packets and each one moves the level by 48 frames, so a burst of
    three exceed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
    [source.rs]
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2026-09-03 Add clock-steered source: put the whole chain back on one clock
    The design was always meant to run one clock end to end — the source board
    steering its I2S to follow the host, so the phone and the I2S link share a clock
    and the only crossing left is at the car, where varying the packet size absorbs
    it without ever dropping a sample.
    Swapping in upstream's PioI2sOut gave that up: it cannot retune its divider, so
    the source board free-runs on its crystal and *creates* a second crossing between
    host and us. The elastic buffer, the slips, the amber and the 10.7 ms cushion are
    all paying for a crossing that the design does not require. That was a deliberate
    trade to avoid unproven PIO, but it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
    [source.rs]
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2026-09-03 Give the source board's iso OUT endpoint packet headroom
    The adaptive path declared the endpoint at 192 bytes while the feedback path
    already used 196. Nominally an adaptive sink receives exactly 48 frames per
    packet, but hosts vary packet size for their own drift management, and a host
    sending 49 frames into a 192-byte endpoint has the packet truncated.
    This is the mirror of the bug that silently dropped every corrected packet on the
    car board's IN endpoint and presented as a click at every packet boundary. Found
    by auditing both directions rather than by hitting it.
    [source.rs]
2026-09-03 Fix reversed stereo on the I2S link
    Verified by ear: the stereo image came out reversed. A SWAP_LR constant on the
    source board's packing corrects it.
    The root cause is not understood, and the comment says so. Tracing the side-set
    bit-to-pin mapping, the WS polarity, the slot order and the push order all say
    the unswapped version should be correct, so one of those assumptions about PIO
    semantics is wrong. Rather than theorise further, this compensates where the
    behaviour is directly observable.
    It is applied on our own master rather than in the car board's receive path
    deliberately: slave_rx keeps the standard I2S convention of WS low = left, so a
    PCM2706 — a known-correct master — wil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
    [source.rs]
2026-09-03 Revert the L/R swap: the I2S mapping was correct all along
    --features pan-test writes a tone into I2S slot 0 and silence into slot 1,
    bypassing USB, the pipe and SWAP_LR. It arrives on the LEFT at the car board's
    output, so the channel mapping is correct straight through and no swap is needed.
    SWAP_LR goes back to false. It was set true on a by-ear report of reversed
    stereo, which the pan test shows was misattributed — the previous commit made a
    correct chain wrong. The constant stays, documented, with a pointer to run
    pan-test before touching it again.
    Also stops pan-test from steering the clock. With the pipe bypassed its level is
    meaningless, so the loop drove the rate down to the 46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
    [source.rs]
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2026-09-03 Add a build that measures the real buffer excursion
    Every figure used to size the cushion so far has been inferred. The "host bunches
    three USB packets" number came from needing a 192-frame deadband in the
    un-steered build — but that build also carried a +64 ppm systematic error, so the
    excursion it was really compensating for may have been drift rather than
    bunching, and the floor may be well below what I claimed.
    --features measure-excursion tracks the peak |off_target| since boot and colours
    the LED by it: green under 64 frames, amber under 128, red at or above. Run a
    full song and the peak is the real lower bound on the cushion.
    [source.rs]
2026-09-03 Car board: follow the source's sample rate instead of muting
    The car board advertised 48 kHz and muted anything else. That was the right call
    when we believed Tesla buzzed at 44.1 — but that turned out to be our own ISO
    transport bug, and the retested matrix has the car playing 32 k, 44.1 k, 48 k and
    96 k cleanly. So following the source beats refusing it, and it defuses the
    PCM2706's unlockable 32/44.1/48 rate list: whatever the phone picks, we carry it.
    embassy-usb builds descriptors once at startup, so changing the advertised rate
    means re-enumerating. The chosen rate is stashed in the watchdog scratch
    registers, which survive a watchdog reset, behind a magic value so power-on
    garbage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
    [car.rs]
2026-09-03 Guard the rate/buffer geometry at compile time, and drop 96 kHz
    Checking whether rate following would be plug and play with a PCM2706 turned up
    a latent fault: `set_rate` scales the deadband with the rate, and a deadband at
    or above the target means the pacer can never correct — the level cannot travel
    far enough to leave the band, so drift accumulates unchecked until the buffer
    hits an end. At 96 kHz the deadband is 192 frames.
    A const assertion now checks every advertised rate leaves room: deadband plus one
    producer burst strictly below target. Verified it bites by temporarily
    re-adding 96 kHz to the low-latency build, which then failed to compile.
    That assertion immediately caught som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
    [car.rs]
2026-09-03 Fix the excursion measurement: ignore startup and settling
    It read red before playback even began. At boot the pipe is empty, so
    off_target() is a full target's worth — the startup transient, not anything about
    the host — and the peak was pinned there before any audio existed. The
    measurement was useless as written.
    It now holds the peak cleared until the pipe primes, clears it again on pause so
    each run measures fresh, and ignores the first ~2 seconds after priming while the
    steering loop pulls the level to target.
    [source.rs]
2026-09-03 Size the source cushion from measurement: add ultra-low
    MEASURE reported the peak buffer excursion stayed under 64 frames (1.33 ms) over
    a full bass-heavy track with the clock steered. That is the first evidence-based
    number for this; every previous cushion was sized from inference, and the
    "3-packet host burst" figure I had been using turned out to include drift from
    the +64 ppm divider bug rather than being bunching at all.
    --features ultra-low takes the source ring to 256 (2.67 ms cushion, 2x the
    measured peak) with a 16-frame I2S block. Ring 128 would sit exactly at the
    measured peak with no margin, which is why the answer to "why not 128" is no even
    now that it has been measured.
    It r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
    [source.rs]
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2026-09-03 Car board: an absent source must be silence, not clicks
    With the source board unpowered, the car board streamed clicks to the car. Two
    causes, both fixed.
    The I2S inputs were floating. slave_rx configured BCK, LRCK and DATA as plain
    inputs with no pull, so an unpowered or unplugged source left them picking up
    noise — and the state machine happily synchronised on spurious edges and pushed
    garbage into the pipe, which the pump then sent to the car. All three are now
    pulled down, so an absent source holds them low, the program blocks on its first
    `wait 1` forever, and no data is produced at all.
    And the capture task could not notice. With no clock the DMA never completes, so
    it blocked inde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
    [car.rs]
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2026-09-03 Relicense the ST7789 driver MIT: the project is now uniformly MIT
    t114/src/st7789.rs and its framebuffer were the only non-MIT files, carried over
    AGPL-3.0-or-later from wireless-performer-fw. The copyright holder owns both
    projects and has relicensed this copy MIT, so the `usb-spy` build is no longer a
    combined AGPL work and there is no longer a licence exception anywhere.
    The headers record what happened rather than just asserting MIT: the originals in
    wireless-performer-fw remain AGPL, and the grant covers this copy only. NOTICE.md
    keeps the provenance for the same reason — a file that changes licence should say
    why, or the next reader has to reconstruct it.
    Verified both T114 builds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
    [framebuffer.rs, st7789.rs]
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2026-09-04 Double-buffer the I2S capture
    slave_rx pushes with noblock, so a full RX FIFO discards the sample rather than
    stalling the state machine. The loop did the whole pipe push between one
    dma_pull completing and the next being armed, with the pump holding PIPE under
    a critical section in that same window, against a FIFO worth about 83 us.
    Arm the next transfer first and process the previous block into a second
    buffer while it runs, so the unattended window drops from a full processing
    pass to a memcpy plus DMA setup.
    Lost samples are invisible downstream — they look like the source running
    slightly slow, not like loss — which is the same failure the nRF firmware had
    when a single-buffered i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
    [car.rs]
2026-09-04 Re-establish I2S frame alignment before the first capture
    Nothing ties a DMA block boundary to a frame boundary. The state machine runs
    from the moment it is enabled while the first DMA is not armed until the
    capture task first runs, so samples accumulate in the RX FIFO — and an odd
    number sitting there when the transfer starts rotates every frame that follows
    by one sample, for the whole session.
    That reads as exchanged channels plus a one-sample skew, and which way it lands
    depends on timing at reset, so it appeared and disappeared between boots.
    Disable, clear the FIFO and restart the program before arming the first
    transfer. Restarting guarantees the next push is a left sample, becau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
    [car.rs]
2026-09-04 Reset the rate detector when the stream reopens
    The detector counts captured I2S frames against USB frames, and USB frames only
    tick while the pump is writing. Across a gap it therefore holds a large capture
    count against no frames at all, and its first window after the stream reopens
    reports an absurd rate.
    An unclassifiable rate mutes, so this was a full second of silence at every
    stream start — and the car toggles alt settings constantly, so it was happening
    throughout normal use, not just at startup.
    [car.rs]
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2026-09-04 Push whole frames from the I2S capture, not single samples
    The previous attempt at this — clearing the FIFO and restarting the state
    machine before the first transfer — cannot work: SM_RESTART clears the shift
    counters but leaves the program counter alone, so the machine can resume
    mid-frame and push half a sample. A recording taken after that fix was still
    rotated: bit-exact at the flat sample level, but offset by an odd number of
    samples.
    Shift both channels into the ISR and push once, so a FIFO word is a whole
    frame. That removes the parity that made this possible at all: the DMA moves
    words, nothing tied a word boundary to a frame boundary, and an odd number of
    samples left in the F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
    [car.rs]
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2026-09-05 Move I2S to a shielded pinout, configured in one file
    An eleven-minute recording compared against the file that was played showed 112
    corrupted samples in its first two and a half minutes. All but one were the
    right channel, and every one had been replaced by its own sign bit —
    (sample & 0xFFFF) >> 15, exactly, on all 54 checked by hand. Jumps reached 44%
    of full scale in a single sample, which is the pop that has been audible for
    weeks. Nothing was lost: no missing frames, and one 16-frame insertion that is
    the pacer doing its job.
    A right slot read fifteen bit-clocks early produces precisely that value —
    fifteen bits of the left slot's zero padding, then one bit of the real sample.
    Th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
    [car.rs, source.rs]
2026-09-05 Rebuild every image on the new pins, and stop the diagnostics drifting
    The pinout change left sixteen tracked images built against GP2/3/4. Two of
    them are what actually gets flashed, so they were rebuilt first; the rest
    followed, along with the wiring tables in README and FLASHING.
    The diagnostics were the dangerous ones. They were built by hand rather than by
    build-uf2.sh, so they kept the old pins silently: I2SSNIFF watches BCK and LRCK
    with plain GPIO inputs and would have reported "no clock arriving" on a link
    that was working, which is exactly the wrong answer from the tool you reach for
    first. It now takes its pins from the same map as everything else, and every
    diagnostic is built b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
    [i2ssniff.rs, i2stest.rs]
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2026-09-05 Add a diagnostic that puts a known tone through the car board's pipe
    packet-stress cannot answer where the holds come from. It writes its tone
    straight into the packet buffer and never touches the pipe, so it cannot produce
    a pipe underrun even if the pipe is the fault — 411 seconds of it came back
    exact, which rules out the USB transmit path and the capture, and nothing else.
    This build substitutes the tone at the other end: in the capture task, where the
    I2S block is pushed into the pipe. The values are replaced, the timing is not.
    The source board still drives the I2S clock, so the producer runs at exactly the
    rate it normally does, and the pipe, the pacer and the packet sizing all beh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
    [car.rs]
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2026-09-05 Measure how the car board's pipe empties, not just that it did
    pipe-tone put the holds in this board's pipe: three in eight minutes with the
    I2S samples discarded, so none of them arrived from the source. Neither cushion
    mattered — doubling it here and on the source changed nothing — which leaves the
    question the pacer's design turns on. It corrects by one frame per packet,
    roughly a thousand frames per second of authority against a mismatch measured at
    under 2 ppm, so a gradual drain is not something it should ever lose. A drain it
    cannot answer is one that arrives faster than it can respond.
    So measure the fall. Sampled once per USB packet, which is 1 ms, and latched on
    the first unde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
    [car.rs]
2026-09-05 Hold the nominal rate when there is nothing to steer to
    `off_target` reads a whole target low on an empty pipe, so with nothing playing
    the steering loop winds the I2S clock down to nearly its clamp — 47488 Hz with
    this cushion — and holds it there for as long as the phone is stopped.
    pan-test already carries a note about exactly this: steering on a pipe it
    bypasses drove the clock to 46 kHz, and the car board rightly muted an
    unrecognised rate. The same thing happens on every ordinary pause, and it is
    audible as a buzz while stopped.
    It also fires a false diagnosis. At 47488 Hz the car's pipe loses 512 frames a
    second, drains from its target in about a quarter of a second, and underru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
    [source.rs]
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
